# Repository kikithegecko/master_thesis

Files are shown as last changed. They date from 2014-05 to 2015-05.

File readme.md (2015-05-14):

### Casual Interation with a Bracelet

Yes, this is my Master thesis. It is about interaction with
a wrist-worn wearable (aka bracelet) and encompassed the
whole design and manufacturing process from the bracelet
itself to the needed electronics, some minituarization steps,
and of course the software. Oh, and the writing.

Here are some buzzwords if you're interested but want to know
if looking through all those files is really worth it ;)

- CAD models for 3D printing
- CAD models for liquid silicone cast
- PCB schematics for Teensy and Arduino shields
- Embedded code for a Bluetooth-controlled RGB light source
- A working implementation of the [3$ Gesture Recognizer](http://www.medien.ifi.lmu.de/pubdb/publications/pub/kratz2010threedollar/kratz2010threedollar.pdf) featuring 3-dimensional Golden Section Search
- A huge LaTeX writeup with lots of progress pictures
- Some slide sets to be used with reveal.js

If you're just interested in pictures, take a loog at my
[flickr profile](https://www.flickr.com/photos/kikidergecko/sets/), I have outsourced all pictures there.

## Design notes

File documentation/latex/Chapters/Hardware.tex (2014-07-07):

\chapter{Hardware}

\section{The Bracelet}

The bracelet consists mainly of an electronic ink display and several touch sensors for conscious interaction and a motion sensor for gesture recognition. The bracelet's design focuses on wearing comfort, low weight and small error of unintended activation.

\subsection{Design Process and Prototype Manufacturing}

The design process for the interactive bracelet presented in this thesis went through different stages. At first, a 3D-printed casing was favored, but later on a cast silicone bracelet turned out to be very comfortable for the user. The different prototypes are explained in detail in the following sections.

\subsubsection{Constant Thickness}

This very simple first approach is basically a rectangular profile rotated around a curve. It has the same magnitude at any point, which makes it quite uncomfortable to wear, especially under a layer of clothing.

\subsubsection{Tapered Shape}

With a tapered shape and non-uniform thickness, this looks more appealing. The reduced wall strength (0.7mm) made it very fragile in fabrication, two (out of two) prints broke during post-processing. Wearing the cuff while working on a PC feels only a little uncomfortable, but twisting the hand is encumbered by the tight-fitting bracelet. Future prototypes sould allow more space between the arm and the bracelet to ensure better comfort.

\subsubsection{Tapered Shape with Lid}

A modified design of Prototype 2 with a removable lid. The structure of the lid turned out to be too fine, especially the flexible part was too thin to work as intended. The size of the bracelet was increased a little so it is more comfortable to wear. Still, the rigid shape leads to clumsiness.

\subsubsection{Amico Bracelet Print-out}

Just a print of the tri-part design by Daniel Muschke on GrabCAD. It turned out to be a little too small, but the style felt more comfortable than the previous prototypes.

\subsubsection{Modified Tri-Part Design}

A re-work of Prototype 3, involving hinge research. The first draft turned out way too small, the second iteration was too big. Further research into this shape was paused because a long, bracelet-like display was considered instead of a small one.

\subsubsection{Silicone Bracelets}

After some consideration on a flexible, bracelet-shaped e-ink display, a prototype from silicone was considered. Mold design turned out a little tricky but finally succeeded. I printed a two-piece mold which only needed a little post-processing to fit properly together. The mold was coated with black spray paint to make the inside a little smoother, but this didn't work as intended so the paining step can be omitted in future mold making processes. The filling holes for the silicone were too small, and the silicone was more viscous than expected.

The first cast with a closed mold and filling through the holes was very unsuccessful, it produced two small end pieces and nothing in between. For following casts, one part of the mold was filled with silicone and closed afterwards, this turned out way better. It is also important in what orientation the mold is placed during dry period, because air bubbles will float towards the ``top'' of the mold, leading to instabilities. Getting the silicone part out of the mold was no problem.

The bracelet design involved a magnet clasp and it turned out as almost impossible to strongly attach magnets to silicone with anything but silicone itself and they will likely jump out of place and snap together if you place them too close in your design.

Two casts were made, one with each of the available silicone mixtures. The softer one was slightly too soft and had a disappealing color. No tests were made yet regarding the tightness of the diplay inside the bracelet.

\section{Interactive Light Source}

The examplary light source for the scenario mentioned at the beginning of this page will be an Arduino-controlled LED strip. Communication with the bracelet will take place via Bluetooth. An Arduino-controlled RGB LED strip with a Bluetooth module. For a color change, the RGB color code is transmitted in a RRRGGGBBB string. Note that all values must have 3 digits, leading zeroes must not be omitted.

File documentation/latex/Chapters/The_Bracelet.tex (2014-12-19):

\chapter{The Bracelet}
\label{chap:bracelet}
As presented in the introduction, this thesis aims to design and implement a wrist-worn wearable. Users should interact with it in a casual way, meaning that the interactions are not interrupting the users' current tasks in contrast to typical smartphone interactions that require focus on the display and input. Instead, the frequently used functions for controlling the ambient light should be executed without needing to look at the device, so that additional cognitive and physical load by either social, mental or physical encumbrance does not prevent the user from interacting with the bracelet.

In terms of hardware design, the device should be comfortable to wear, even for a longer period of time. To increase acceptance of potential users, the bracelet should not feel more clumsy than a wristwatch and the material has to be skin-friendly. Regarding the interaction design, gestured input as well as a touch sensor that enables sliding interaction need to be included. Although direct feedback of interaction is given by the controlled light source, a minimal form of visual feedback can help the user when in doubt about correctly triggering specific features. In order to communicate with the ambient light, the bracelet needs some form of wireless communication. The device's processor needs to be fast enough to analyze in-air gestures without perceptible delay.

Regarding those constraints, the interactive bracelet consists of several touch sensors, a motion sensor, a status \ac{LED} and a Bluetooth communication module, all powered by an ARM microcontroller. The bracelet's design focuses on wearing comfort, low weight and small error of unintended activation.

\section{Manufacturing Techniques}

All bracelets produced for this thesis were designed using a 3D \linebreak\ac{CAD} modeler. The first prototypes were 3D printed rigid bodies to wear as arm cuffs, but those designs turned out to be too inflexible and uncomfortable to wear. The need for a different material for the bracelets arose, so a transition from printing to casting with liquid silicone was necessary. The molds are printed, assembled, filled with silicone and usually destroyed while retrieving the finished cast.

This section will explain the various methods and tools used for designing and manufacturing the bracelet prototypes in detail.

\subsection{Computer Aided Design}
% http://www3.ul.ie/~rynnet/parametricmodellingbasics-solidworks.php
In the beginning of a design iteration, a model of the desired object is created with a 3D \ac{CAD} program. For all designs in this thesis, the open source \ac{CAD} modeler FreeCAD \cite{freecad} was used. This program classifies itself as a general purpose 3D parametric modeler. A typical work-flow when designing a bracelet is as follows:

A bracelet's model is based on a sketch defining the inner circumference of the future bracelet. As the human wrist does not follow a circular shape, all designs made for this thesis are based on an oval circumference. In FreeCAD, this is realized by a composition of arcs and straight lines. It is important to constrain the sketch with radii, lengths and angles as well as symmetries or perpendicular constraints until no degrees of freedom are left and thus the model is fully constrained. If the model is missing some constraints, the export process or the printing of the model can raise errors or alter the design in an unintended way.

In the next step one or more cross sections are added to various points along the circumference. They define the thickness and shape of the bracelet at said points. For increased comfort, the bracelet should be as slim as possible, especially on the ``backside'' below the palm. In more complicated designs, an alternative to complex sketches for the profiles is the creation of multiple, overlaid sketches as a preparation for a subtraction operation in the later process. All profiles need to be fully constrained as well.

\begin{figure}[bth]
	\myfloatalign
	\subfloat[Fully constrained inner circumference]
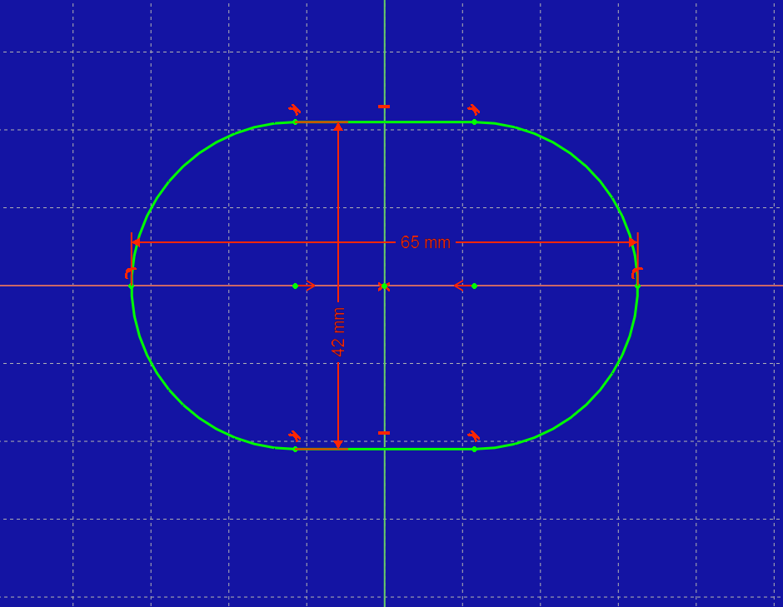
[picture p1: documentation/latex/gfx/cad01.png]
	{} \quad
	\subfloat[Added profile for sweeping around the circumference]
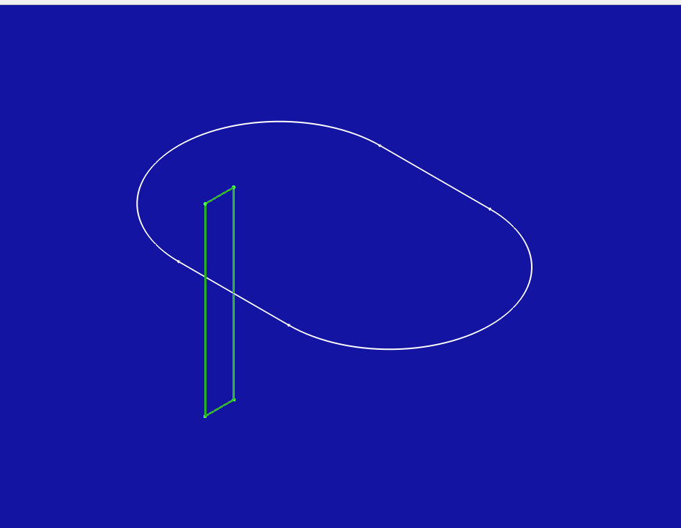
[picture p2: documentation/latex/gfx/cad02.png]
	{} \\
	\subfloat[Result after sweeping]
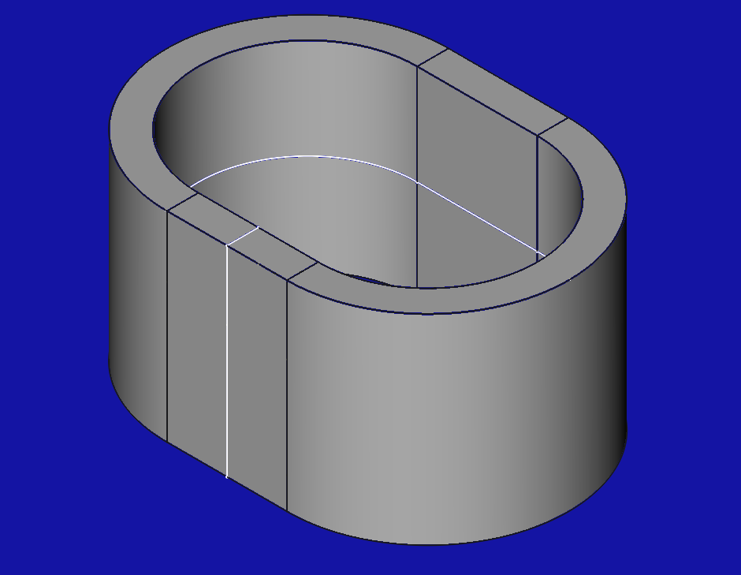
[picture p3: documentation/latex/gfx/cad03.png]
	{} \quad
	\subfloat[\ac{CAD} model after using a boolean subtraction operation]
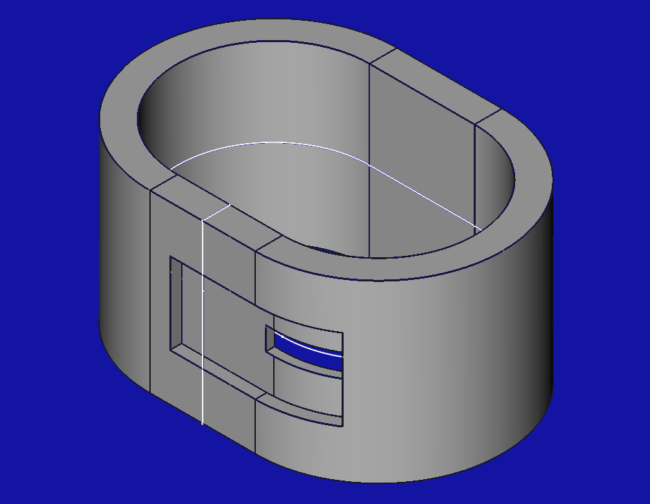
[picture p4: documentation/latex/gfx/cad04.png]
	{}
	\caption{Steps in designing a bracelet prototype in FreeCAD.}
	\label{fig:cad}
\end{figure}

After the circumference as well as one or more profiles are added to the design, a first solid is created by sweeping the profile(s) around the circumference curve. This operation creates a basic shape that can be refined further on, typically by chamfering or filleting the edges to increase wearing comfort. If a complex shape is desired, multiple sweeps can be generated and used in boolean operations such as union or subtraction. This is the usual approach for most bracelet designs. Figure \ref{fig:cad} illustrates these steps.

The last step in the design process is usually the finishing of the \ac{CAD} model. In case of the bracelet, this translates to edge smoothing with chamfer or fillet tools. Smoothed edges increase the overall wearing comfort of a bracelet, so they are very desirable on edges in contact with the skin.

The finished designs are then exported as mesh files (usually in \ac{STL} format) for printing.

\subsection{3D Printing}
All prints were manufactured using a ProJet360 3D printer \cite{printer}. The model is created by printing the binder fluid onto a plaster-like powder bed in the build area. After each printed layer, a new thin layer of powder is added to the print bed. The ProJet360 allows for a layer thickness of 0.1 mm \cite{datasheet_printer}. This allows even delicate structures without any additional supports, since the printed object is surrounded and therefore supported by plaster powder during the production process. The only drawback of this printing process is that it doesn't support closed, hollow objects since there is no possibility of removing the enclosed excess powder after the process has finished. When designing models for 3D printing, this constraint has to be kept in mind.

The finished object is then carefully removed from the build bed and any excess powder is gently brushed or blown off. The printer offers a cleaning chamber with a pressurized air pistol and a vacuuming system to assist in that task. Without further hardening, the objects are very fragile and easy to break, even with the pressurized air pistol included in the printer. In order to drastically increase the strength of the prints, they are infiltrated with a fluid after they were thoroughly cleaned. Prints produced by the ProJet 360 can be infiltrated with one of three different substances with varying characteristics: The ColorBond ``instant-cure infiltrant'', the two-part StrengthMax infiltrant ``ideal for functional models'', and the Salt Water Cure ``eco-friendly and hazard-free infiltrant'' \cite{datasheet_printer}. All prints produced for this thesis were infiltrated with ColorBond.

The infiltration step adds strength and hardens the material, resulting in a sturdy printed object. However, the objects created with this technique are very rigid and any bending load breaks them easily. Wall strengths of $1.5$ mm and up have been proven sturdy enough for a bracelet shape, although this also depends on the object geometry.

\subsection{Silicone Casting}
% http://www.npl.co.uk/science-technology/mass-and-force/hardness/rubber-hardness
% https://www.google.com/patents/US1770045
% http://www.calce.umd.edu/TSFA/Hardness_ad_.htm#3.5
% ISO 7619 for scale OO?
Another manufacturing process for bracelet prototypes used in this thesis is liquid silicone casting. Two different types of silicone were used for making various bracelet prototypes, both from manufacturer Smooth-On: Sorta-Clear 37 and Mold Star 15 Slow.

The most important characteristic for silicone in prototype production is the hardness, measured in Shore (after Albert F. Shore) or Durometer. It measures the indentation of a material with a special device which is also called Shore Durometer. It consists of a hardened steel rod with a finer tip and is available in two versions, since there are two different scales for Shore hardness (cf. table \ref{tab:shore}). The Shore A scale is designed for softer materials and the Shore D scale for harder ones, but they do overlap, so a material classified in Shore D hardness is not necessarily harder than another material classified in Shore A hardness. Each scale ranges from values 0 to 100, higher numbers indicate higher material resistance. The Shore hardness is specified in EN ISO 868.

\begin{table}
	\myfloatalign
	\begin{tabularx}{\textwidth}{clcc} \toprule
		\tableheadline{Type} & \tableheadline{Configuration} & \tableheadline{Diameter} & \tableheadline{Spring Force}\\ 
		\midrule
		A & $35\degree$ & $1.4$ mm & $8.06$ N \\
		D & $30\degree$ & $1.4$ mm & $44.46$ N\\
		OO & $1.2$ mm in spherical radius & $2.4$ mm & $1.11$ N \\
		\bottomrule
	\end{tabularx}
	\caption[Test setups for Shore hardness types]{Test setups for Shore hardness types A, D, and OO \cite{ASTM2240}}  \label{tab:shore}
\end{table}

When dealing with silicone, the Shore A scale is sometimes too ``hard'' for soft rubbers. Another standard therefore specifies twelve different Durometer types, where the OO scale is commonly used for soft silicones \cite{ISO7619}. Figure \ref{fig:shore} shows the three Shore hardness scales A, D, and OO, as well as some examples for everyday objects and their corresponding Shore values.

\begin{figure}[bth]
	
	\caption[Shore hardness scales and everyday examples]{Shore types A, D, and OO in comparison with everyday examples of various hardnesses. \cite{smoothon-web}}\label{fig:shore}
\end{figure}

The silicone rubbers used for casting bracelet prototypes are both located on the Shore A scale. The softer Mold Star 15 Slow has a Shore A hardness of 15 that could be roughly compared to that of a rubber band according to figure \ref{fig:shore}, while the slightly harder Sorta-Clear 37 has a Shore A rating of 37, similar to that of a pencil eraser \cite{moldstar} \cite{sortaclear}.

Both silicone products consist of two compounds that have to be added up and stirred before casting. While the Mold Star silicone has a rather low viscosity, casting the Sorta-Clear requires careful mold design, since it does not distribute well and is rather viscous. A vibrating table can help in filling the mold completely, but nonetheless were casts with the Sorta-Clear silicone much less fruitful, especially for the detailed molds of the one-piece designs (cf. section \ref{sec:silicone-prototypes}).

\section{Design Process and Prototype Manufacturing}

The design process for the interactive bracelet presented in this thesis went through different stages. At first, a 3D printed casing for the electronics was favored, but turned out to be too rigid, too fragile and even cumbersome while worn on the wrist. Later on, a cast silicone bracelet turned out to be more comfortable for the user. The different prototypes are explained in detail in the following sections.

\subsection{Rigid Designs}

The first approach that comes to mind when thinking about bracelet design is a cuff-like, rigid shape. From the\ac{CAD} point of view, the first bracelet prototype consists of a single rectangular profile rotated around a oval curve which was derived from a measured wrist. The bracelet's inside is hollow, in order to store all the electronic components. The cuff's gap was just large enough for the wrist to fit through, although in reality, this lead to light scratches on the skin in combination with the rough texture of the printed material. In addition, the uniform thickness made this first prototype uncomfortable to wear, especially at the open ends. 

To summarize, the uniform thickness made the bracelet feel uncomfortable on the wrist and the material felt unfriendly to the skin. So this fist prototype had some clear downsides that were eliminated in the next iteration.

\begin{figure}[bth]
	\myfloatalign
	\subfloat[\ac{CAD} view]
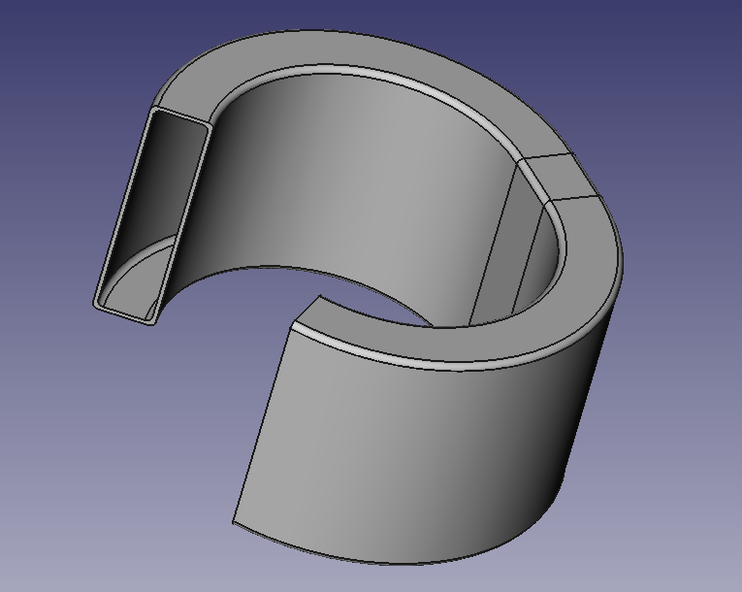
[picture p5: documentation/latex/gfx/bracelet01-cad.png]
	{} \quad
	\subfloat[Printed bracelet]
	{\label{fig:bracelet01}%
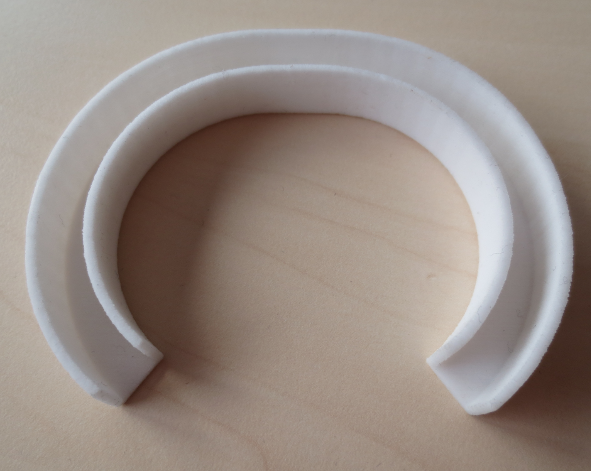
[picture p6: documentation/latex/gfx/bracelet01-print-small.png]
	}
	\caption{First rigid design with uniform thickness}
\end{figure}

In the following iteration, a bracelet of varying thickness was designed to make wearing the prototype more comfortable. The part on top of the wrist was designed to have the highest thickness, since this spot is only rarely disturbing in typical wrist movements and users are likely accustomed to some extra mass on this spot from wearing wristwatches. As the bracelet bends around the arm, its thickness decreases and shrinks to a minimum at the cuff gap. Decreasing the thickness from $10$ mm to $3$ mm made the look more appealing and wearing a little less encumbering. At the same time, the wall strength was decreased from $1$ mm to $0.7$ mm, which made it very fragile in fabrication and usage: Both prints broke during post-processing. Additionally, the possibility of storing electronic components inside the bracelet decreased, since smaller ends featured smaller entrances to the hollow inside. Wearing the cuff while working on a PC felt only slightly uncomfortable, but twisting the hand was still encumbered by the tight-fitting bracelet. 

All in all, a tapered shape felt more comfortable, but the downsides of the material were still present and the improved shape led to less practicability from the engineering point of view. A design goal for future prototypes derived from this prototype was adding more space between the arm and the bracelet to ensure better comfort while wearing it.

\begin{figure}[bth]
	\myfloatalign
	\subfloat[\ac{CAD} view]
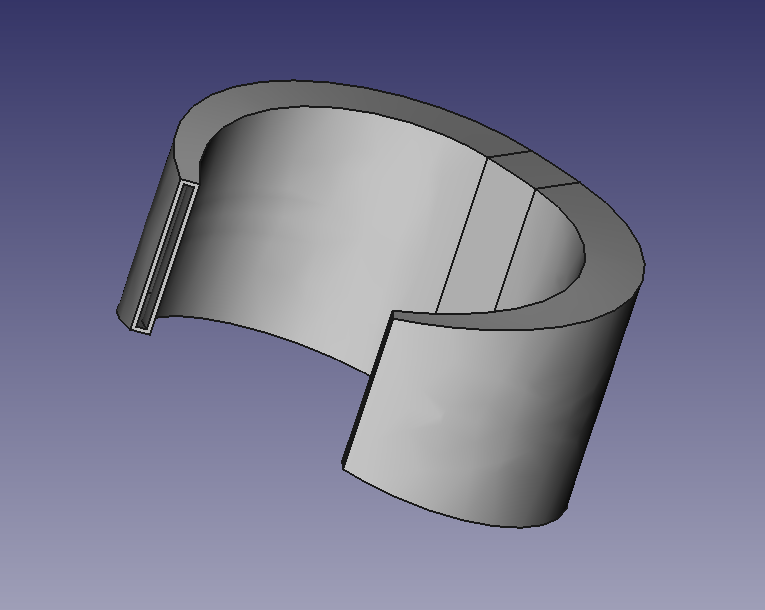
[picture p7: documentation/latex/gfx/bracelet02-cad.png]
	{} \quad
	\subfloat[Printed bracelet]
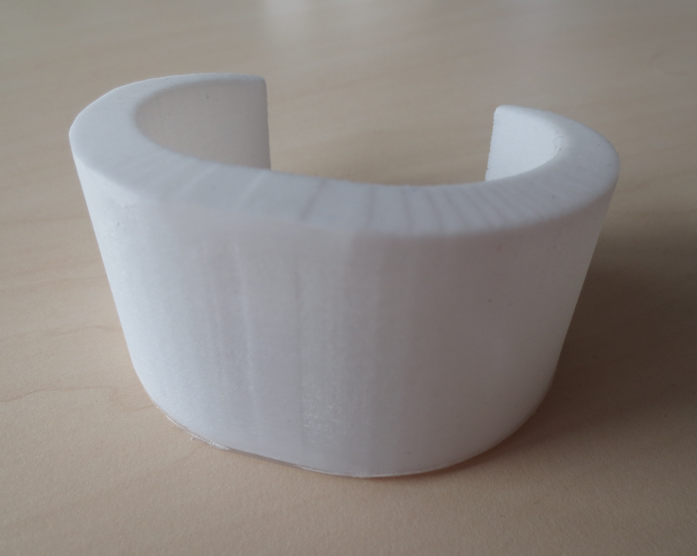
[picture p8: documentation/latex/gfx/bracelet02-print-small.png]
	{} \\
	\subfloat[Top view]
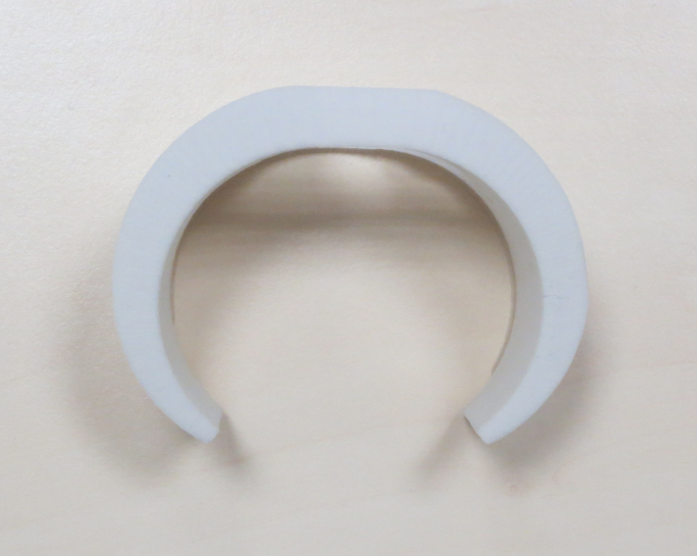
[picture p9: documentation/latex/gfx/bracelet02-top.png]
	{} \quad
	\subfloat[End detail]
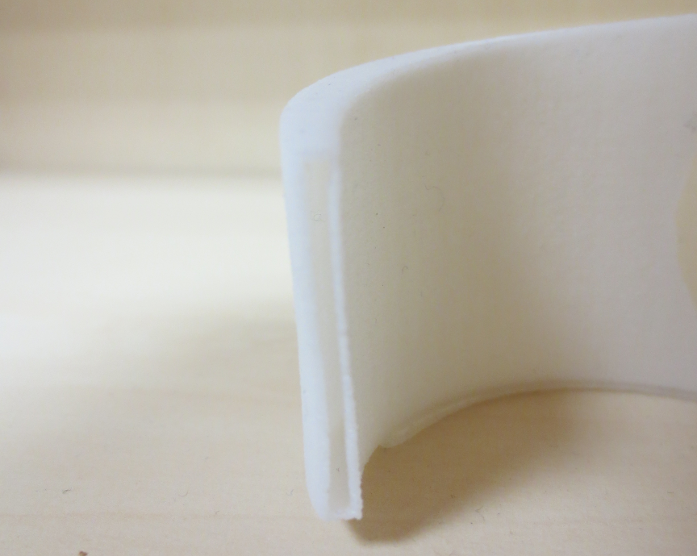
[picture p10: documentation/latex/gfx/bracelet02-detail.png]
	{}
	\caption{Second design featuring a tapered shape}
	\label{fig:bracelet02}
\end{figure}

A modified design of the aforementioned prototype featured a removable lid since the tapered shape made it hard to access the inside space of the bracelet. The lid design was inspired by battery case covers commonly found in remote controls or small electronic devices. It features two rabbets on the one side that support the lid in its place and another, smaller rabbet with a cavity in the material right next to it, so the rabbet can snap just inside the lid gap when it closes.

\begin{figure}[bth]
	\myfloatalign
	\subfloat[Lid in \ac{CAD} view]
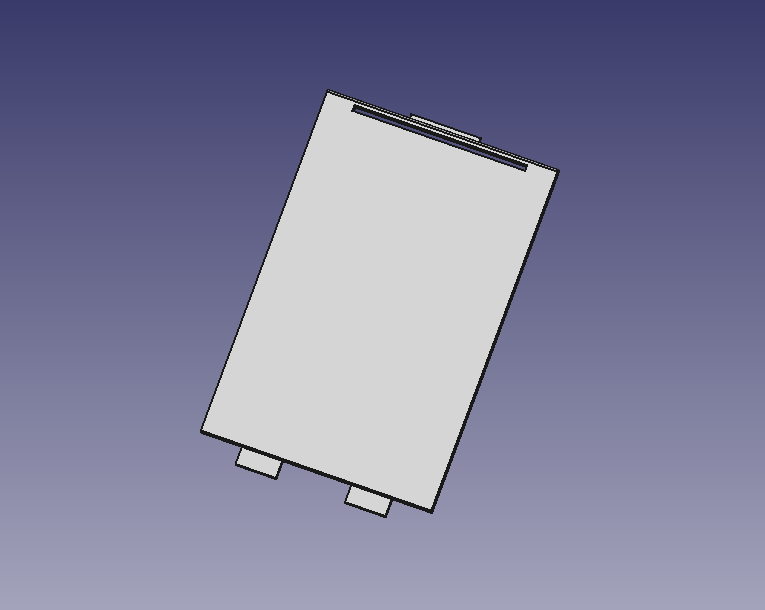
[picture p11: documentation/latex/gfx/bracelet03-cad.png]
	{} \quad
	\subfloat[Printed bracelet]
	{\label{fig:bracelet03}%
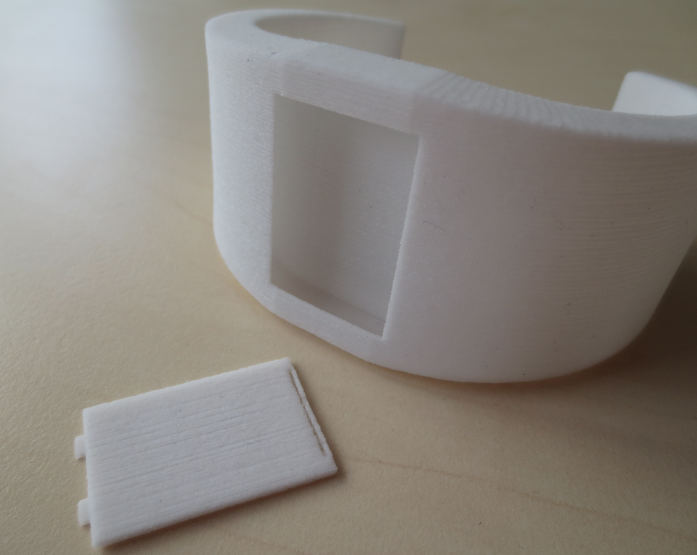
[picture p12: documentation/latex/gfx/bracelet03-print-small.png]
		}
	\caption{Third design with removable lid}
\end{figure}

It turned out that the lid features were designed too finely, especially the flexible part was too thin to work as intended. The lid had to be opened and closed very cautiously and overall, the construction seemed not reliable for daily use. In addition, the rigid shape still lead to clumsiness in wearing the bracelet, so the whole concept of rigid bracelets was abandoned.

\subsection{Segmented Designs}

The search for a more flexible printed bracelet shape lead to an entry for an activity bracelet design contest by Daniel Muschke on a 3D printing template exchange site called \textit{GrabCAD} \cite{amicobracelet}. Muschke created a \ac{CAD} file for a bracelet consisting of three segments that are connected by slow hinges, i.e. hinges with great resistance that do not move if no external force is applied. This design considered electronic components like a micro-controller and a micro \ac{USB} port which made a good start for further modification, but unfortunately the file format made it impossible to alter the design in detail. A print was possible since \ac{STL} files were included in the upload. However, the design turned out to be too small to be actually wearable, but it demonstrated that printed hinges work well with a pivot made from wire. The style felt more comfortable to wear than the previous prototypes and felt leaner on the wrist than the rigid prototypes. Overall, the printed design looked promising so the idea of a multi-part bracelet was investigated further.

Recreating Muschke's design was not as easy as planned, since the parametric modeling approach on this segmented shape was very different compared to previous designs. The first prototypes were based on a wrist-like oval circumference curve, while the multi-part design originated from a partitioned circle, since all parts should have the same dimensions in length and curvature. Adjusting the part size to the designated wrist turned out to be difficult, and prints of the design were either too small or too big when printed.

The bracelet segments are hollow and open on the side that lays to the wrist. This leaves enough space for storing electronics. Since the parts are only connected by hinges, routing the necessary wires between the segments needs to be considered, e.g. by leaving small holes right next to the hinges.

\begin{figure}[bth]
	\myfloatalign
	\subfloat[\ac{CAD} view]
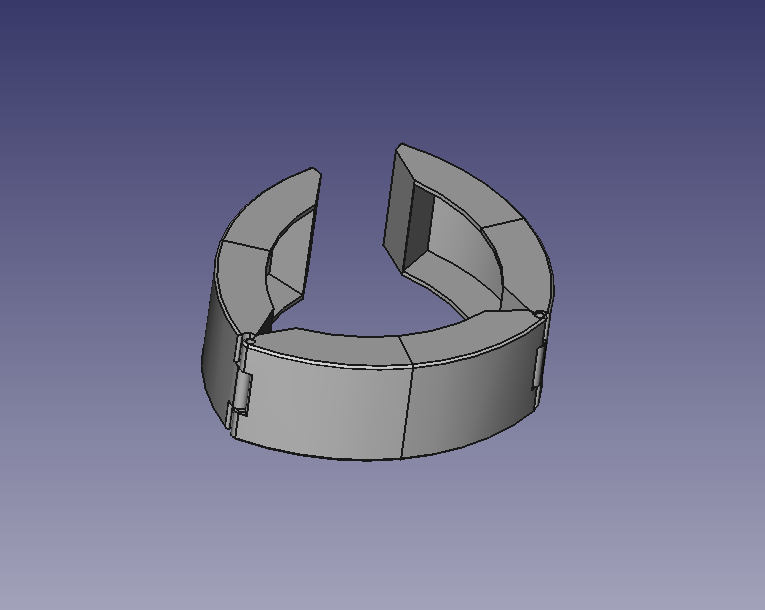
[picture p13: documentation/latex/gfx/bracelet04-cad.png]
	{} \quad
	\subfloat[Hinge Detail]
	{\label{fig:bracelet04}%
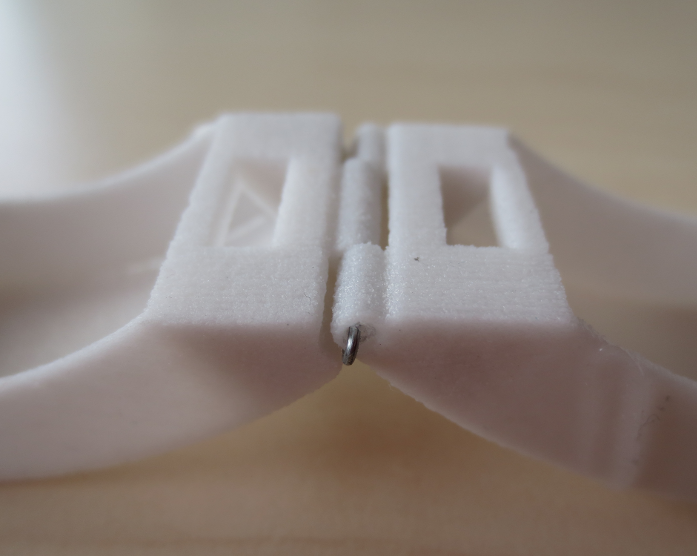
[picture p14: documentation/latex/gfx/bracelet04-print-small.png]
		}
	\caption{Multi-part design}
\end{figure}

Since the manufacturing possibilities at the \ac{HCI} group don't allow for slow hinges (as the inspiration by Muschke suggests), a different solution for keeping the bracelet closed while worn on the wrist needed to be found. A magnet clasp with small neodymium magnets was tested, but attaching them turned out to be more difficult than expected. When attached to the inside of the segment tips, the magnetic force was too weak to reliably keep the bracelet together. Mounting the magnets on the outside of the segments resulted in mounting difficulties, since the magnetic force of neodymium magnets is considerably strong,  which frequently resulted in torn glue layers.

When an electrophoretic display was considered as a part of the bracelet, the segmented approach became undesirable, since in addition to aforementioned difficulties during design and manufacture, the usable surface space was relatively small when it came to hosting a single big component like a display. This issue led to further research into various other manufacturing techniques and potential materials for bracelet prototypes, and, eventually, to cast silicone.

\subsection{Silicone Bracelet}
After some consideration on a flexible e-ink display, a prototype brace\-let made of silicone was considered. The molds used in the casting process were designed and printed similarly to the bracelets presented in the previous sections. However, designing a mold was significantly more difficult.

As with the previous 3D printed prototypes, the bracelet positive was designed first. The flexibility of silicone allows for some features that weren't practical when implemented in rigid material, such as e.g. cavities for electronic components. This resulted in more complex bracelet concepts. In addition, closing mechanisms like magnets had to be considered in this design stage.

When the \ac{CAD} process for the positive is finished, the mold is designed by adding surrounding geometries to the model and applying boolean difference operations. If reusability is desired for individual mold components or the whole mold, the geometry and constellation of the mold parts need to be planned carefully; therefore the characteristics of the printed material have to be taken into consideration. For example, tunnels in the resulting silicone bracelet are not possible if the mold is meant to be used more than once.

Another important aspect of mold design is planning the casting process. Some types of silicone rubber are more viscous than others, and the mold design needs to make sure that the liquid rubber reaches all corners and delicate parts well. The distribution inside the mold can be supported by applying gentle vibration during the cure process. However, this assumes that the liquid silicone is already distributed into most regions of the mold.

The first silicone design was a simple strap with an open pocket for the long electrophoretic display which was considered as a feature of the bracelet at that time in the design process. The closing mechanism relied on molded neodymium magnets for which some cavities were featured in the bracelet design.

Mold design turned out a little tricky but finally succeeded. A two-piece mold was printed which needed a little post-processing to fit properly together. To ensure a proper fit when closed, small tongues and grooves were added to the mold parts. The mold's inside was coated with black spray paint to make it a little smoother, but this didn't work as intended so the painting was omitted in future mold making processes. The filling holes featured for the silicone were too small, and the mixture was more viscous than expected, so the first cast failed and resulted in two small end pieces and nothing in between. Figure \ref{fig:silicone01} (a)-(c) illustrates some steps in this process.

\begin{figure}[bth]
	\myfloatalign
	\subfloat[Unpainted molds]
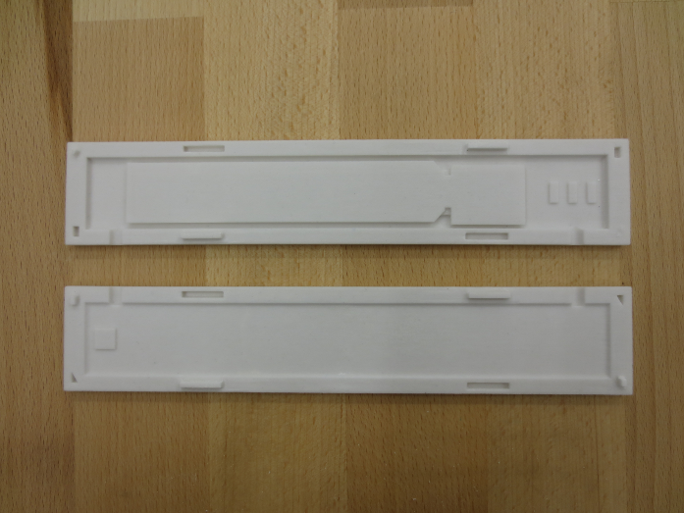
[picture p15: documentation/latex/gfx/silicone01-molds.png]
	{} \quad
	\subfloat[Closed molds with filling holes]
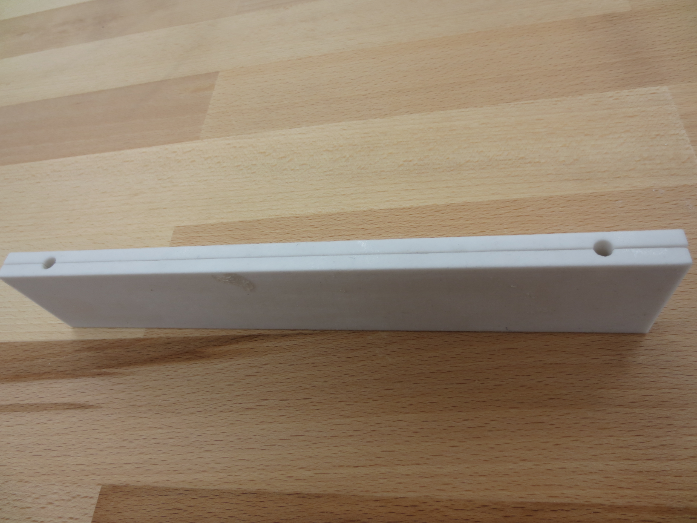
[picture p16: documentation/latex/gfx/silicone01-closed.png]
	{} \\
	\subfloat[Result after first cast through filling holes]
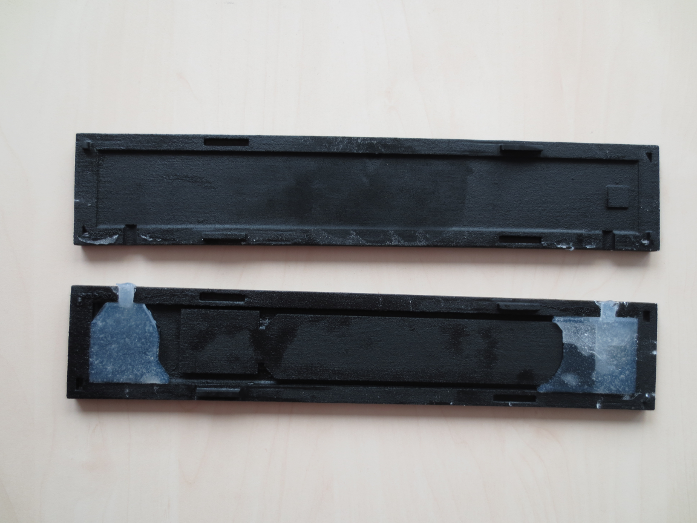
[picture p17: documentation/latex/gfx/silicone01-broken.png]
	{} \quad
	\subfloat[Result after second cast by filling the mold directly]
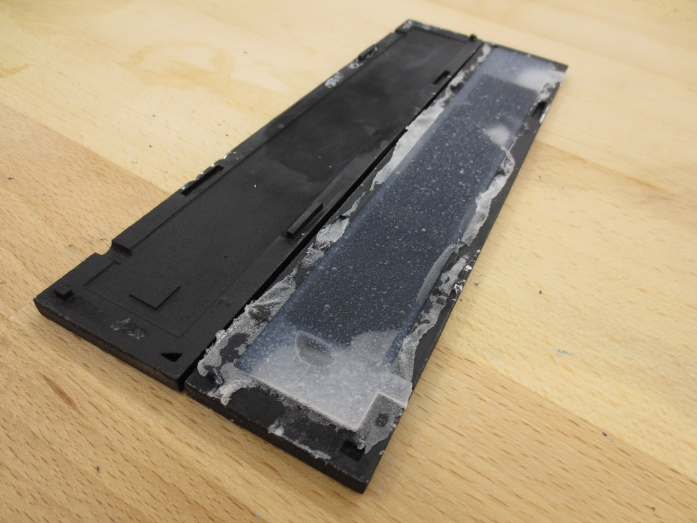
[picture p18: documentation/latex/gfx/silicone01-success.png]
	{} \\
	\subfloat[Successfully cast bracelet]
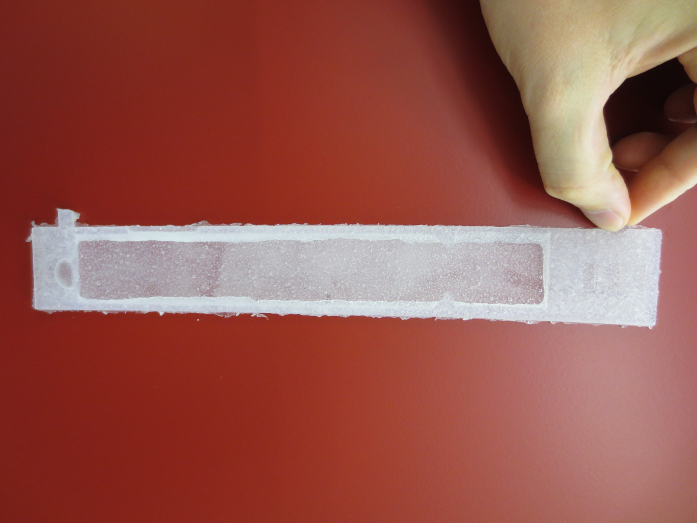
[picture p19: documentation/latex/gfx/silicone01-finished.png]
	{} \quad
	\subfloat[Bracelet with attached magnets]
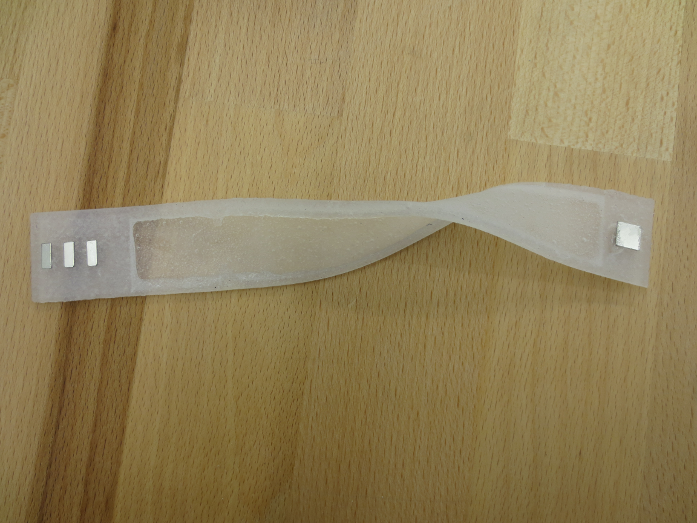
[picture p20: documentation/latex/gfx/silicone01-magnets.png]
	{}
	\caption{Manufacturing of a silicone bracelet using a two-piece mold}
	\label{fig:silicone01}
\end{figure}

For following casts, one part of the mold was filled with silicone and closed afterwards; those casts turned out significantly better (cf. \ref{fig:silicone01} (d)-(e)). The orientation in which the mold is placed during the dry period is also relevant, as air bubbles would float towards the ``top'' of the mold, leading to instabilities when oriented inappropriately. After the liquid silicone's curing period, retrieving the cast from its mold was unproblematic.

This first rubber bracelet design involved a magnet clasp (see fig. \ref{fig:silicone01} (f)), but it was infeasible to reliably attach magnets to silicone with anything but silicone itself and they would likely jump out of place and snap together if placed too closely to each other in the design. Apart from that, the silicone felt much more comfortable on the skin and was perceived as less obstructive while worn on the wrist. The possibility of attaching components by placing them in pockets or cavities resulted in thinner bracelets in general.

Two casts were made, one with each of the available silicone mixtures. The softer one was slightly too soft and in addition, the rims were too short, so the display would jump out of place almost instantly when bending the bracelet. With this knowledge and the positive impressions of the material itself, more silicone designs were produced and manufactured.

\subsection{One-Piece Silicone Bracelet}
\label{sec:silicone-prototypes}
The next design was a ring-like silicone bracelet in one piece, so the issue with closing mechanisms became obsolete. The mold for this prototype consisted of three pieces, an outer and an inner ring as well as a bottom plate to properly align those rings. Due to the very rigid printed material, the molds could not be recovered after the cast and had to be destroyed in order to retrieve the bracelet. To prevent unnecessary waste of material, the wall strength was reduced to $2.5$ mm, which turned out to be strong enough to survive assembly and the casting process. The advantage of using one-time molds was the possibility to add tunnels to the design. This was used in some models, especially for the display area to hide cables or bulky connectors. Figure \ref{fig:bracelethistory} gives an overview of the various design iterations.

\begin{figure}[bth]
	\myfloatalign
	\subfloat[The first design featured a large cavity for a flexible electrophoretic display]
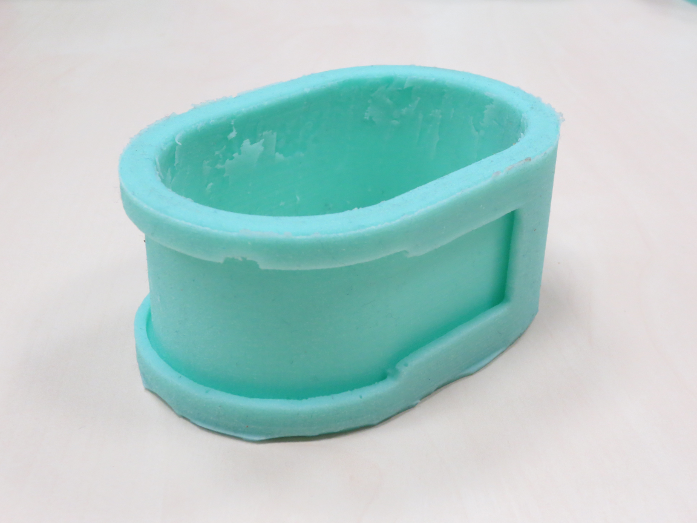
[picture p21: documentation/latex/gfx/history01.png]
	{} \quad
	\subfloat[The second design introduced a small tunnel]
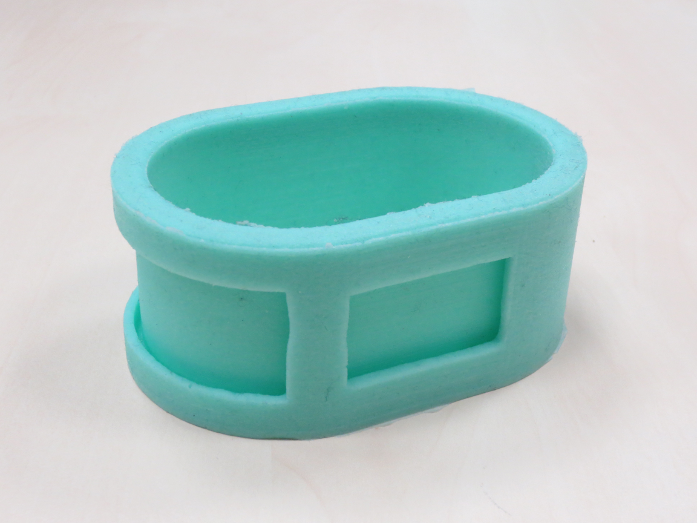
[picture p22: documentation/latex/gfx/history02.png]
	{} \\
	\subfloat[The third design replaced the display by a touch strip and featured a cavity for the Teensy]
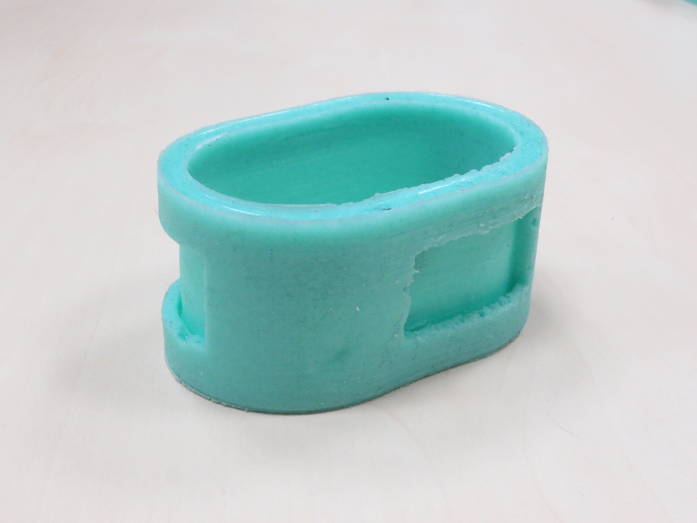
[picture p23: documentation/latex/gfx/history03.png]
	{} \quad
	\subfloat[The final design with varying thickness and a big cavity for the Teensy]
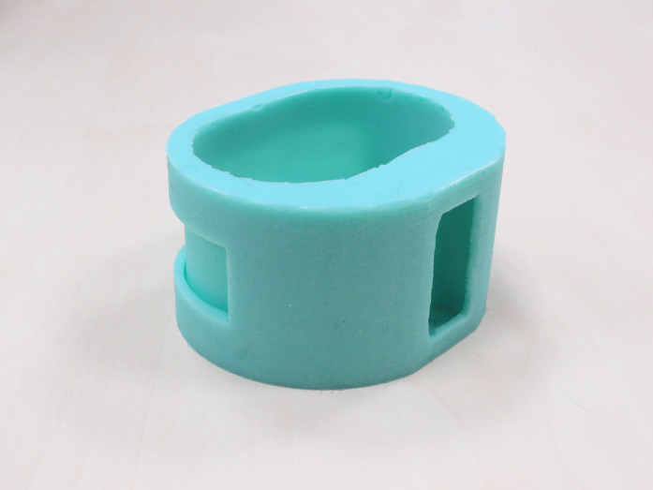
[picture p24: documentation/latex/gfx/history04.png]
	{}
	\caption{History of the one-piece bracelet prototyped manufactured for this thesis}
	\label{fig:bracelethistory}
\end{figure}

The molds for one-piece bracelets were harder to fill with material than the previous one. Especially the Sorta-Clear silicone was too viscous to fill the complete mold, resulting in broken casts. The green MoldStar silicone turned out to work quite well, but sometimes it would leak through little gaps between the rings and the base plate, so a thorough assembly was vitally important. Remaining gaps were closed with hot glue in later iterations. In addition, a simple self-made vibrating plate helped distributing the silicone to all parts of the mold and reduced the number of air bubbles in the cast. 

The first one-piece bracelet designs included an electrophoretic display and featured wide cavity rims to hold said display in place. First wearing tests were successful. When the display was omitted later on, the cavities stayed to hold a capacitive touch surface in place. After the final hardware configuration took form, another cavity for the electronics was added to the design. Since the hardware was thicker than the bracelet, the spot to house it needed to come thicker. The board was eventually placed on the inner wrist and connects to the touch element with a short flat wire cable along the bracelet's surface. It is powered by a micro USB cable attached to a port on the lower rim of the bracelet. A status \ac{LED} is visible through the silicone on the upper rim above the electronics.

\begin{figure}[bth]
	\myfloatalign
	\subfloat[Front view]
	{} \quad
	\subfloat[Back view]
	{} \\
	\subfloat[Top view]
	{} \quad
	\subfloat[Incorporated electronics]
	{} \\
	\subfloat[Teensy with custom shield]
	{}
	\caption{The final bracelet prototype}
	\label{fig:siliconefinal}
\end{figure}

\section{Teensy Development Board}
The core part of the bracelet's electronics is the Teensy USB development board, which is built around a MK20DX256 32 bit ARM Cortex-M4 Processor running on 72 MHz clock speed \cite{teensy_web}. The Teensy can be programmed using the popular Arduino IDE and thus can profit from the extensive existing libraries and code examples for the Arduino family.

Like many Cortex processors, the Teensy's chip has direct capability to process capacitive touch input. It also features the \ac{I$^2$C} protocol for communication with other components (see also section \ref{sec:accel}), several serial communication ports and an integrated programmer to enable flashing via \ac{USB}. However, the processor includes no floating point computation unit, which slows down calculations that feature floating point numbers.

\section{Touch Slider}
The major input interface of the bracelet is a touch surface which consists of seven cut copper foil segments that are placed in a zigzag pattern (cf. figure \ref{fig:sketch-touch}). This capacitive strip can either be used as an array of seven individual buttons or as a single large surface that can detect swiping gestures or a primitive variant of multi-touch interaction.

\begin{figure}[bth]
	\myfloatalign
	\begin{center}
	
	\end{center}
	\caption{Sketch for the capacitive touch slider}
	\label{fig:sketch-touch}
\end{figure}

Capacitive touch is based on the concept of a parallel plate capacitor. The copper foil segments act as a capacitor's plate, the human hand touching them represents the other plate. Since the capacitance is proportional to the area of the plates, larger segments lead to increased sensitivity. The definition of a plate capacitor's capacitance $C$ is defined as follows:
\[
	C = \frac{A\epsilon}{d}
\]
Where $A$ represents the area of the plates, $\epsilon$ is a material constant of the dielectric between the plates and $d$ is the distance between the plates. This shows that the capacitance changes more when the finger is close to the sensor and less when it's farther away \cite{Camacho2010}.

Touch sliders can be compared to a potentiometer and return an analog value for the finger's position on the slider \cite{Camacho2010}. The usual layout of a touch slider features several neighboring electrodes, in the context of this thesis, a slider with seven electrodes was designed and built. This option was chosen since the Teensy has a restricted number of capacitive sensing enables pins from which some were already in use for other components, since almost all pins of the chip serve multiple functions.

\begin{figure}[bth]
	\begin{center}
	
	\end{center}
	\caption{The capacitive touch strip used in the final bracelet prototype.}\label{fig:touch}
\end{figure}

A zigzagged pattern of the slider's electrodes supports microstepping, i.e. considering the logical combinations of multiple electrodes pressed at the same time to achieve a higher resolution in position detection \cite{Camacho2010}. The touch slider used in this thesis was made using an electronic vinyl cutter with copper tape. The slider is depicted in figure \ref{fig:touch}.

\section{3D Accelerometer}
\label{sec:accel}
Another interaction interface of the bracelet is a MMA8652FC three-axis digital accelerometer \cite{datasheet:mma8652}. In a micromachined device like the one used in this thesis, a seismic mass is attached to delicate ``springs'' in order to measure the acceleration. Both components are usually made of silicon. When an acceleration occurs, the electric capacitance between the seismic mass and the fixed frame changes and the occurring acceleration can be derived accordingly. Note that one such mechanism is only able to detect acceleration along a single axis. Since the MMA8652FC is a three-axis accelerometer, it contains one mass-spring-system for each of the three axis.

\begin{figure}[bth]
	\myfloatalign
	
	\caption[Block diagram of the MMA8652FC digital accelerometer]{Block diagram of the MMA8652FC digital accelerometer \cite{datasheet:mma8652}} \label{fig:accel}
\end{figure}

In addition to this basic accelerometer functionality, the MMA8652FC also features a range of embedded microprocessing functions, as depicted in the component's block diagram (fig. \ref{fig:accel}). Out of those functions, the ``Single, Double \& Directional Tap Detection'' was used predominantly. This module can detect tap interactions, which can be visualized as spikes in the acceleration along one specific axis. The detection process can be configured in detail to adjust factors like the tap intensity or the duration between the two taps of a double tap. When tap detection is enabled, a single register's content indicates if such a tap has occurred. The detailed configuration used for single and double tap recognition in context of this thesis is discussed in section \ref{sec:config}.

In order to communicate with the bracelet's processor, the accelerometer implements the \ac{I$^2$C} communication protocol which was developed in 1982 by Philips Semiconductor (now NXP Semiconductors) and became public domain in 2006 when the underlying patent expired. By using two lines for a clock signal (\textsc{SCL}) and data transmission (\textsc{SDA}) respectively, data can be interchanged in a master-slave system at varying bit rates. Figure \ref{fig:i2c} illustrates this process. To initiate communication, the Teensy incorporates the role of a master device and begins a transmission by changing the \textsc{SDA} value from high to low while \textsc{SCL} is on high. Now the bus is considered busy until the master sends the Stop condition and the actual data request and transmission can take place.

\begin{figure}[bth]
	\myfloatalign
	
	\caption[Data transfer on the \ac{I$^2$C} bus]{Data transfer on the \ac{I$^2$C} bus \cite{i2c}} \label{fig:i2c}
\end{figure}

To request register data from the accelerometer, the master writes the address of the desired register on \textsc{SDA}. Note that no further synchronization between master and slave device is needed, since the slave adapts the clock signal on \textsc{SCL} which is determined by the master device. After sending the register's address, the Teensy indicates the end of the transmission without sending a Stop signal. The accelerometer acknowledges the received data and proceeds to send the requested register's contents, and finishes by terminating the connection with a Stop command, which is generated by switching \textsc{SDA} from low to high while \textsc{SCL} is on high. Both lines now stay high due to connected pull-up resistors. If the next register's content is requested, the process starts again with a Start signal transmitted by the master \cite{i2c}.

\section{Visual Feedback}
To provide visual feedback to the user, an \textsc{RGB} \ac{LED} is incorporated in the bracelet. Since most changes are reflected by the connected light source with no perceptible delay, the \ac{LED} serves mainly as an indicator for the recognition of single and double taps in the context of precise color changes and gesture recognition.

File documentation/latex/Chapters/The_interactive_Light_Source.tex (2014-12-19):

\chapter{Interactive Light Source}
\label{sec:lamp}

The previously mentioned light source for the scenario is built around a 12 V powered RGB \ac{LED} strip, which can be purchased for home lighting or car decoration. It is approximately $5$ m long and features three \ac{LED}s on each $5$ cm long segment. The original controller box which included an \ac{IR} receiver for a remote was removed and replaced by an Arduino Uno \cite{arduino_uno} with a custom shield. 

The shield features a Roving Networks RN42 Bluetooth module \cite{datasheet_rn42} and some transistors for switching the voltage on or off. The whole setup is powered by a standard 12 V power supply and encased in a spherical lamp shade made from translucent glass in order to diffuse the spotted impression of the LED strip (cf. figure \ref{fig:lamp}).

\begin{figure}[bth]
	\begin{center}
		
	\end{center}
	\caption{The interactive light source, encased.} \label{fig:lamp}
\end{figure} 

Communication with the bracelet takes place via Bluetooth. The RN42 module implements the Bluetooth \ac{SPP} and can be accessed easily with the \texttt{SoftwareSerial} module from the Arduino standard library. The lamp is configured as a Bluetooth slave, the bracelet acts as the master device. For command transmission, a serial connection is established over the Bluetooth link between the devices. Once it is set up, the master transmits a nine-digit string composed from three values from $000$ to $255$. Note that all values must have three digits, leading zeros must not be omitted. These values represent the intensities of the red, green, and blue channel respectively. The algorithm on the Arduino feeds them into the platform's analog outputs which feature \ac{PWM}. These outputs are connected to the red, green, and blue channels of the \ac{LED} strip and so the light color changes. A simple fading algorithm prevents disruptive flashing while switching colors.

It turned out that the RGB \ac{LED}s use a lot of current, a test with an adjustable power supply yielded that the lights become much brighter with increased current. The power supply was limited to $5$ Ampere and there was no saturation in brightness indicated at this level. However, the standard power supply mentioned above serves only $2250$ mA which results in less brightness. A way to improve this would be to shorten the \ac{LED} strip by cutting off several segments.

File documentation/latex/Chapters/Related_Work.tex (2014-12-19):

\chapter{Related Work}
Casual interaction has been explored by other researchers.

Pohl and Murray-Smith have researched casual interaction with everyday electronics like smartphones. They coined the term ``casual interaction'' in contrast to focused interaction. They described that in many situations in daily life, the user would not receive periodic feedback from the interacting device or not interact with it in a constant, uninterrupted fashion due to physical, social or mental reasons like wearing gloves in the winter or being exhausted after a day of work. Instead of giving up control over the device in such situations, the user should be able to control the level of focus to which they would like to engage \cite{Pohl2013}. The underlying distinction between foreground and background interaction in the context of technology has been introduced by Buxton in 1995, where he described improvements on telemetry systems. As a background interaction between humans, the office cameras of the system's participants take periodic stills and check if all members of a scheduled video conference are at their desks. Once all participants are available, the software actively asks to set up a conference and thus switches to foreground interaction. This relieves the user of periodically interrupting her work and checking if all participants are available \cite{Buxton1995}.

Interaction with intelligent lighting in public space as well as in the arts has been researched by Seitinger et. al. The \textit{Urban Pixels} project encouraged users to interact with flexible \ac{LED} light sources which pose an alternative to current urban display systems \cite{Seitinger2009}, while the \textit{Light Bodies} project focused on people's interactions with and reactions to portable light sources that respond to sound and vibration \cite{Seitinger2010}. In both cases, the users enjoyed manipulating the lights and were eager to interact with them, often in a playful fashion.

Wearable electronic devices have been very present in the recent years. Activity trackers like the Fitbit bracelets \cite{fitbit} record the wearer's movement data and calculate statistics on daily activity, e.g. the number of stairs the user has climbed or the distance she rode by bicycle. Activity trackers thus aim to help the wearers in getting to know their daily habits and reaching goals in personal activity. Smart watches connect to mobile phones using Bluetooth, they display various notifications along with the current time, allow for music playback control or aid in navigational tasks. They are either universal like the Pebble \cite{pebble} or bound to a certain phone like Samsung's Galaxy Gear \cite{galaxygear}.

More recently, attempts to add ``social'' features to wrist-worn smart devices have been made. The \textit{iBand} concept by Kanis et. al attempts to augment virtual social networks by merging their information about a person into real-world interactions with people. The device  triggers an automatic exchange of contact information if two users perform a handshake. Furthermore, the user can personalize a displayed logo and ``collect'' other users' emblems by exchanging contact information with them \cite{Kanis2005}. As a commercial product, the Razer Nabu smart band can exchange contact information on a handshake and detect other nearby users. The product merges these ``social'' functions with an activity tracker as described above \cite{razernabu}.

Controlling devices in the smart home is mostly realized by trigger-action programming as discussed by Ur et. al. On the IFTTT platform, users can create simple ``if, then'' rules for linking a broad range of actions between different software or devices, allowing only one trigger and only one action per rule. Ur et. al. discovered that a model like this for expressing rules would suffice to formulate behavior for the smart home if more flexibility in formulating the rules was allowed \cite{Ur2014}. A more complex approach to controlling the smart home is the use of middleware like \textit{Android Wear} for customized applications and use of an app store, allowing to pick the right applications for the smart home components available \cite{androidwear}.

Regarding new shapes and configurations of wrist-worn wearables, research has come up with various concepts. The \textit{Facet} bracelet features multiple displays and allows users to rearrange apps between them or extend a single app over multiple segments \cite{Lyons2012}. Kim et. al. implement remote control of other devices by performing hand gestures which are recognized by the \textit{Gesture Watch}, a set of proximity sensors worn on the wrist \cite{Kim2007}. The \textit{Snaplet} flexible touch display consists of an electrophoretic display augmented by sensors that can detect the current shape of the device. Bending the display causes \textit{Snaplet} to change its function (e.g. phone, media player) or allows the user to navigate through menus \cite{Tarun2011}. Ni and Baudisch even suggest reducing the size of the wearable device to a tiny worn sensor that uses the surrounding skin on the arm or any other body part as an input canvas for touch and gesture input, so that the device blends in with the user's clothing or skin. Despite their small size, users are still able to issue various commands and enter text by using a graffiti gesture alphabet \cite{Ni2009}.

For gesture recognition, two major algorithms that originate from the field of machine learning are very present in research projects. The Gesture and Activity Recognition Toolkit \textit{GART} has been developed by Lyons et. al. and is based on Hidden Markov Models, a statistical model also used in fields like speech or writing recognition \cite{Lyons2012}. \textit{GART} has been used by the aforementioned \textit{Gesture Watch} \cite{Kim2007} and the \textit{AirTouch} device, an around-device gesture recognition device that gives tactical feedback in form of vibrations \cite{Lee2011}. Several other gesture recognizing wearables implement Dynamic Time Warping, another algorithm from the field of machine learning that matches temporal sequences that very in speed \cite{Ashbrook2010} \cite{Liu2009}. In contrast to those computation-heavy and complex algorithms, Wobbrock et. al. have developed a simpler, geometry-based gesture recognizer for touch screen interaction that compares shapes against templates by scaling, translating and rotating them while measuring the distance to find a minimum \cite{Wobbrock2007}. The algorithm was extended to 3D accelerometer data by Kratz and Rohs \cite{Kratz2010}. The recognizer was designed as easy to implement and functional even on embedded devices with limited computation capabilities.

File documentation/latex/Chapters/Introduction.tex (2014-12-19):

\chapter{Introduction}
\label{sec:intro}
Today, Smartphones are our digital assistants for of daily life, and at present, wrist-worn wearables are emerging to take the interweaving of online and offline life one step further. This comes with many advantages and new possibilities, but also amplifies current issues in daily life with those gadgets. While those devices often call the attention of the user, their design around a touch-enabled screen forces the user to concentrate on the device while interacting with it. This usually distracts the user from his or her current context in daily life and forces him or her to interrupt the current task in order to interact with the device \cite{Pohl2013}.

As explained previously, interaction usually requires the full attention of the user. This doesn't suit the way we use our electronic devices in daily life. Since the user is not always able or willing to fully focus on a device, most mobile interaction is perceived as annoying or interrupting, since it often interrupts all other things the user is doing at that moment. Due to physical, mental or social obstructions, which can be either temporary or permanent, a user might not be able to interact with a device as intended \cite{Pohl2013}. This can cause life with the new gadgets to be perceived as rather more frustrating instead of enriching.

\textit{Casual Interaction} can improve the relationship between users and devices. Limiting the required focus for a task to a suitable minimum and designing the interactions in a way that the user can decide how much effort she wants to put into it offers the flexibility needed in a life with the Internet of things. The concept is showcased in the following scenario in context of the \textit{Smart Home} and ambient light control.

\begin{quotation}
	Alice comes home from grocery shopping. While carrying her shopping to the kitchen, she quickly turns on the light by simply touching her bracelet.
	
	After storing everything, she decides to relax in the living room by reading a book. After turning the kitchen lights off by covering the bracelet with her hand, she makes herself at ease on the sofa and picks up the book. To feel more comfortable, Alice dims the living room light a little by covering the bracelet's touch surface and tilting her wrist, just as she was turning a dimmer knob. The living room lights dim accordingly, so she doesn't need to look any closer at the bracelet.
	
	Later that day, Alice prepares dinner and the dining table in the living room. She uses the bracelet's touch controls to specify the exact setup for each light in the room, picking exact colors by sliding and tapping on the bracelet. Alice saves three lighting setups together with unique activation gestures: A warm setting for their guests' arrival and enjoying the welcoming drinks, a well-matched dining setup with focus on the table and foods, and a darker, colorful mood for drinking cocktails after dinner. Changing between these presets with hand gestures allows Alice to focus on her guests and on the meal instead of wasting time and focus by fiddling with wall panels or switches.
	\end{quotation}
	
This scenario illustrates multiple levels of casual interaction with a device: A simple on/off function by covering the bracelet's touch surface does not need sight on the device or high precision, this task is easily accomplished even when the user is distracted or encumbered. Likewise eyes-free brightness dimming by covering the bracelet's capacitive surface and tilting the wrist is only slightly more complex, but this complexity is countered with increased intuition, since the interaction is closely related to the motion of turning a dimmer knob. Detailed color change by precise touch and a fine-tuned hue setup using focused touch interaction represents another level of complexity in which cognitive as well as physical attention is required. In addition, three hand gestures are available to easily access frequently used setups like bright white work light or slightly dimmed relaxing illumination.

In order to enable the interactions mentioned above, the device requires certain features. First, it should stay where it is needed without encumbering the user. Typical remotes or smartphones occupy at least one hand for every interaction they offer. This is not desired, so traditional hand-held devices do not fit the scenario presented above. Instead, there is the need for a wearable device that is attached to the body without getting in the way during everyday activities.

Second, touch-free interaction (i.e. control by gestures) should be possible to enable the above-described casual interaction scenarios. Capacitive touch input offers flexibility and versatility compared to traditional keypads and enables gesture touch input. In addition, the required hardware should be kept on a low cost level and encompass only needed components to keep energy consumption at a minimum, since every recharge procedure is cumbersome for the user.

A bracelet-type device can fulfill the requirements stated above. It is slim and doesn't encumber the user, it can be worn on the arm all day.

This thesis presents the conception, design, prototyping, manufacturing as well as programming of an interactive electronic bracelet for ambient light control in the \textit{Smart Home}. Pros and cons on different materials for wrist-worm wearables as well as a description of the incorporated electronic parts and an overview of the hardware prototyping process can be found in chapter \ref{chap:bracelet}. A short summary of an exemplary interactive light source is presented in chapter \ref{sec:lamp}, while chapter \ref{sec:interaction} focuses on casual interaction and the ways to interact with the bracelet in great detail as well as their technical implementations. Chapter \ref{chap:evaluation} summarizes the lessons learned in the process of designing and manufacturing the bracelet, as well as impressions perceived by potential users. The thesis closes with a conclusion and an outlook on possible future work in this field (cf. chapter \ref{chap:conclusion}).

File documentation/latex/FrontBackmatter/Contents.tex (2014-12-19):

%*******************************************************
% Table of Contents
%*******************************************************
%\phantomsection
\refstepcounter{dummy}
\pdfbookmark[1]{\contentsname}{tableofcontents}
\setcounter{tocdepth}{2} % <-- 2 includes up to subsections in the ToC
\setcounter{secnumdepth}{3} % <-- 3 numbers up to subsubsections
\manualmark
\markboth{\spacedlowsmallcaps{\contentsname}}{\spacedlowsmallcaps{\contentsname}}
\tableofcontents 
\automark[section]{chapter}
\renewcommand{\chaptermark}[1]{\markboth{\spacedlowsmallcaps{#1}}{\spacedlowsmallcaps{#1}}}
\renewcommand{\sectionmark}[1]{\markright{\thesection\enspace\spacedlowsmallcaps{#1}}}
%*******************************************************
% List of Figures and of the Tables
%*******************************************************
\clearpage

\begingroup 
    \let\clearpage\relax
    \let\cleardoublepage\relax
    \let\cleardoublepage\relax
    %*******************************************************
    % List of Figures
    %*******************************************************    
    %\phantomsection 
    \refstepcounter{dummy}
    %\addcontentsline{toc}{chapter}{\listfigurename}
    \pdfbookmark[1]{\listfigurename}{lof}
    \listoffigures

    \vspace*{8ex}

    %*******************************************************
    % List of Tables
    %*******************************************************
    %\phantomsection 
    \refstepcounter{dummy}
    %\addcontentsline{toc}{chapter}{\listtablename}
    \pdfbookmark[1]{\listtablename}{lot}
    \listoftables
        
    \vspace*{8ex}
%   \newpage
    
    %*******************************************************
    % List of Listings
    %*******************************************************      
	  %\phantomsection 
    \refstepcounter{dummy}
    %\addcontentsline{toc}{chapter}{\lstlistlistingname}
    \pdfbookmark[1]{\lstlistlistingname}{lol}
    \lstlistoflistings 

    \vspace*{8ex}
       
    %*******************************************************
    % Acronyms
    %*******************************************************
    %\phantomsection 
    \refstepcounter{dummy}
    \pdfbookmark[1]{Acronyms}{acronyms}
    \markboth{\spacedlowsmallcaps{Acronyms}}{\spacedlowsmallcaps{Acronyms}}
    \chapter*{Acronyms}
    \begin{acronym}[PWM]
    	\acro{CAD}{Computer-Aided Design}
    	\acro{GSS}{Golden Section Search}
    	\acro{HCI}{Human-Computer Interaction}
    	\acro{HSL}{Hue Saturation Lightness}
    	\acro{I$^2$C}{Inter-Integrated Circuit}
    	\acro{IR}{Infrared}
        \acro{LED}{Light Emitting Diode}
        \acro{MIT}{Massachusetts Institute of Technology}
        \acro{MSE}{Mean Square Error}
        \acro{PCB}{Printed Circuit Board}
        \acro{PWM}{Pulse-width Modulation}
        \acro{RGB}{Red-Green-Blue}
        \acro{SPP}{Serial Port Profile}
        \acro{STL}{Sterolithography}
        \acro{USB}{Universal Serial Bus}
    \end{acronym}                     
\endgroup

\cleardoublepage

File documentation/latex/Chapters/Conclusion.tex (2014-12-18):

\chapter{Conclusion and Future Work}

This thesis presents the conceptualization and realization of casual interaction with a smart bracelet coupled to an ambient light source. The whole design process, from interaction conceptualization, hardware and software design to fabrication of the electronic components and implementation of the algorithms is taken into account and presented in a comprehensive manner. The focus lies on the design of interactions with a bracelet, so that frequently used tasks pose the least amount of interruption and require the least amount of focus from the user.

First impressions of potential users were positive, however a proper user study is required to confirm the acceptance of the device and the ways a user can interact with it. A possible study design would center on keeping the user distracted with different tasks while request him or her to operate the bracelet.

Revising the bracelet's software is likely required before planning any further work. From the first informal evaluation, some improvements for the interaction design can be derived and implemented. The gesture recognition algorithm needs to be optimized for the processor and converted into integer arithmetic. In addition, the Bluetooth module needs some extra fine tuning to flawlessly work with the lamp. Features and optimizations like this often go beyond the scope of a strictly time-constrained thesis.

For the future, the bracelet can be evaluated in combination with several other devices. Music playback control is an example that easily comes to mind, for example. Since the hardware is designed very generic in terms of usage applications, a great part of the thesis is easily reusable. In addition, the whole design and manufacturing process was laid out in detail, so that future designers of wearable prototypes can benefit from the past experiences.

The insights gained from the interaction design can be applied to other wearable devices which are worn around the wrist. For example, a smart watch could implement the bracelet's functionalities if a touch sensing wristband was added to it. This way, the insights gained from this thesis could be easily applied to future research or product design.

%TODO final sentence?

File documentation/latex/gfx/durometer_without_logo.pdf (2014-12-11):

0 10 20 | 30 | 40 | 50 | 60 | 70 | 80 | 90 | 100
0 | 10 | 20 | 30 | 40 | 50 | 60 | 70 | 80 | 90 | 100
0 10 | 20 30 | 40 | 50 | 60 | 70 | 80 | 90 | 100
EXTRA SOFT | SOFT | MEDIUM
SOFT

MEDIUM
HARD | HARD | EXTRA HARD

SHORE 00

SHORE A

SHORE D


GEL SHOE
INSOLE


‘GUMMI’ JELLY
CANDY


RUBBER BAND | PENCIL ERASER | TIRE TREAD | SHOE HEEL | SHOPPING CART WHEEL

HARD HAT

# SHORE HARDNESS SCALES

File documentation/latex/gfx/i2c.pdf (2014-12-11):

SDA; SCL; MSB; ACK; 002aac861; START or repeated START condition; STOP or repeated START condition; acknowledgement signal from slave; byte complete, interrupt within slave; clock line held LOW while interrupts are serviced; acknowledgement; signal from receiver

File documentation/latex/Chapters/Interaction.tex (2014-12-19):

\chapter{Interaction}
\label{sec:interaction}
In order to satisfactorily interact with the device, depending on physical, mental or social distractions, the user should be able to use the bracelet in different ways. Tasks that occur frequently should be completed in a very casual way, because tasks with low cognitive requirements are most likely still possible to execute successfully while the user is distracted. Rather infrequent tasks are allowed to demand more of the user's attention and cognitive capacity. If they occur rarely, the dissatisfaction of a failed task because of insufficient focus is not as grave as it would be if the task was a frequent one and if it would thus fail often.

As introduced in section \ref{sec:intro}, the user should be able to turn the lights on or off with a minimum of engagement, so the task would still be possible while, for example, physical encumbrance hinders the user from performing more complex interactions. Also, the action should not require more effort than moving to the wall switch and pressing it. 

A similar amount of or only slightly increased complexity in interaction should be required for dimming the lights, because this is also a frequently used function in daily life. The analogy of turning a dimmer knob makes this interaction easy to associate with its function. Dimming should be performable while under some degree of distraction, for example while participating in a conversation. Since both hands and a focused rotational movement are needed, acceptable physical distractions quickly reach a tolerance limit.

More focus could be required for changing the color in a fuzzy way, according to the concept of \textit{mood} derived from color psychology, on a loose range from calming to stimulating. Since this function would probably not be used very often, an interaction which requires a glance on the device to locate the proper spot for touching is considered reasonable. 

Changing the exact appearance of the light in terms of color, brightness and saturation however requires concentration and focus on the task, therefore the associated interaction with the bracelet can demand more of the user's engagement. Picking a certain template of presets in light color and setting is also a rather complex cognitive task that would happen infrequently, so associating it with a focused interaction seems appropriate.

\begin{table}
	\myfloatalign
	%$\left \Downarrow 
	\begin{tabularx}{.95\textwidth}{cc}
		\toprule
		\tableheadline{Task} & \tableheadline{Associated Interaction}\\ 
		\midrule
		switching on/off & covering touch area\\
		adjusting brightness & covering touch area, twisting the wrist\\
		fuzzy mood change & touch on two specific segments\\
		precise color change & combination of touch, slide, tap\\
		picking preset template & double tap and hand gesture\\
		\bottomrule
	\end{tabularx}
	%\right \downarrow $
	\caption[Tasks and associated interactions with the bracelet]{Tasks and associated interactions with the bracelet, in ascending complexity of the interaction and decreasing occurrence of the task}  \label{tab:interaction}
\end{table}

Table \ref{tab:interaction} shows how different interactions correspond to the described tasks. The focus in matching them lies on the required amount of attention needed to successfully complete the interaction as well as on the cognitive load a certain interaction entails. 

Since switching the lights on or off occurs rather frequently, a very simple action was associated with it. Covering the whole touch area of the bracelet for a few moments will trigger the on or off function of the device. When twisting the hand while covering said area, the light dims accordingly (cf. figure \ref{fig:onoff}). 

More complex tasks have more intricate interactions associated with them, for changing the lighting \textit{mood} a precise touch on two neighboring segments of the touch surface is required. This demands either a precise knowledge of the bracelet's shape and the layout of its components, or a concentrated glance at the touch surface in order to choose the right segments. Figure \ref{fig:mood} depicts this interaction.

A precise adjustment of the light in terms of hue, saturation and brightness requires even more focus on the task, since not only the function itself requires some concentration, but also the execution of the associated action does (cf. figure \ref{fig:hslinteraction}). To activate this settings mode, a single segment needs to be pressed, then the three attributes are set by sliding along the touch surface and switching to the next one with a tap on the bracelet's back side. After the last tap, the device returns to its ``standard mode'' in which all described functions are available.

The interaction of drawing a gesture in the air to pick a preset template for the lights was ranked the most complex in table \ref{tab:interaction}, although the physical requirements are not as high as in the previously described task of changing the color. In this case, the cognitive requirement of correctly remembering a movement pattern's association to a certain light configuration is higher than the physical requirement to execute the gesture correctly. There are three preset gesture actions for setting a bright work atmosphere, a dimmed and warm-colored relaxing environment and a colorful lounge mood, respectively. Gesture recognition is triggered with a tap on the bracelet's back, as illustrated in figure \ref{fig:hslinteraction}.

In the following sections, the various interaction levels with the bracelet and their underlying algorithms will be described in detail.

\section{Pairing the Bracelet with a Light Source}
The bracelet's Bluetooth module automatically searches for nearby devices and connects to a range of matching IDs without any interaction or confirmation by the user. This can pose a security risk to spoofing a lamp device, but since no sensitive data is handled by either participant, the impact would rather be an annoying disturbance than a serious threat to privacy.

\section{Switching the Light Source on and off}
\label{sec:onoff}
Since turning the lights in a specific room on or off is a frequently used interaction, it should require little complexity in terms of cognitive as well as physical workload, i.e. a simple, easily memorable way of interaction is desired. For those reasons, simply covering the touch surface with the whole hand (cf. fig. \ref{fig:onoff}) and holding for approximately $1.5$ seconds will result in switching the lights on or off, depending on the current state. Within this constraint, there is a tolerance of one segment when checking if the whole touch surface is covered, so that covering six out of seven capacitive segments would still trigger this function.

\begin{figure}[bth]
	\myfloatalign
		
	\caption{Covering and holding the bracelet's touch surface for on/off switching or dimming} \label{fig:onoff}
\end{figure}

While the touch slider is covered, the hand must be held fairly steady in terms of rotation to correctly trigger the on/off function, because otherwise the dimming algorithm would trigger instead. See section \ref{sec:dimming} for a specification of the tolerated rotation when covering the touch area. If the light is switched off, the current color would be saved by the bracelet and restored on the next ``on'' command.

\section{Adjusting the Light Source's Brightness}
\label{sec:dimming}
Apart from switching the lights on or off, a change in brightness is the second most desired interaction in the smart lighting scenario. For example, the desire of watching TV in the living room benefits from a dimmed light setting. However, if the user fails to locate the remote control for the television, a quick dim interaction towards brighter light facilitates the search for the missing remote control. After the item is found, the brightness level of the room's lighting can easily be dimmed back to the desired setting.

The dimming interaction is different from the other use cases, since there exists a physical solution for this task in form of dim knobs for wall outlets. Usually, those wall dimmers are rotary knobs connected to a potentiometer which dims the light source by increasing the electric resistance. Hence, the interaction of turning a knob for dimming the light level is an association for many people.

The intention was to preserve this association to make the interaction with the bracelet more intuitive. The dimming interaction is a combination of twisting the wrist while covering the bracelet's touch surface, imitating the interaction with the wall dimmer. The cover check routine is the same as described in section \ref{sec:onoff}, so covering six of the seven segments suffices to activate this function. While the touch surface is covered, the angle of the wrist rotation is constantly measured. From the way the accelerometer is mounted on the bracelet, the relevant axis for rotation is the Y-axis in the accelerometer's coordinate system. The following formula derives an angle $\alpha$ from the acceleration data \cite{Abayarjoo2013}:
\[ 
\alpha = tan^{-1}\left(\frac{y}{\sqrt{x^2 + z^2}}\right).
\]
Note that the accelerometer data must not include a gravity offset. If the observed angle exceeds certain thresholds and the current angle is at least $0.5\degree$ different from the previously measured value, a dimming step is executed and the brightness of all three color channels is reduced or increased by 10 percent. A counterclockwise movement (from the user's point of view) reduces the brightness, while a clockwise twist increases the brightness.

\section{Changing the Lighting Mood}
In addition to changing the brightness, the user should be able to adjust the light's color in a casual way and without thinking too much about the desired color in detail. Hence, the user is able to change the \textit{mood} of the light by touching two neighboring segments of the bracelet's touch element. Activating the left pair of segments increases the blue channel by one percent every $10$ ms while decreasing the red channel by one percent every $10$ ms; a touch on the right pair of segments causes the opposite (cf. fig. \ref{fig:mood}). Since blue colors are perceived as calming and relaxing while reds and oranges have an activating and stimulating effect \cite{Rosenstein1985}, this function can actually affect the user's mood by utilizing insights of color psychology.

\begin{figure}[bth]
	\myfloatalign
	\subfloat[Coodling down the light \textit{mood} by increasing the blue channel]
	{} \quad
	\subfloat[Warming up the light \textit{mood} by increasing the red channel]
	{}
	\caption{Touch interaction for \textit{mood} change} \label{fig:mood}
\end{figure}

\section{Precise Touch Input for Color Change}
Since adjusting the light color in a rather fuzzy way as described in the previous section is sometimes too imprecise, an additional function for setting the exact light color has been implemented. The RGB color model used by the lamp (cf. chapter \ref{sec:lamp}) is not very intuitive to the average user in terms of expressing a specific color in fractions of red, green and blue light, respectively, so the \ac{HSL} color model was used instead for this interaction.

\begin{figure}[bth]
	\myfloatalign
	\subfloat[The RGB color model, represented as a cube]
	{} \quad
	\subfloat[The \ac{HSL} color model, represented as a cylinder]
	{}
	\caption[Comparison of the RGB and \ac{HSL} color models]{Comparison of the RGB and \ac{HSL} color models, CC-BY-SA Michael Horvath} \label{fig:color}
\end{figure}

While the \ac{RGB} color space forms a cube with red, green and blue channel on each axis, the \ac{HSL} color space forms a cylinder. Hue represents the angle, while saturation stands for the diameter and lightness for the cylinder's height. Figure \ref{fig:color} illustrates that difference. Since the conversion from \ac{HSL} to RGB color space is not trivial, a conversion algorithm had to be implemented (\cite{qwertie}, derived from \cite{graphicsgems}). For given hue $H\in \left[ 0\degree , 360\degree \right]$, saturation $S\in \left[ 0, 1\right]$ and lightness $L\in \left[ 0, 1\right]$, the chroma value $C$ is calculated first:
\[
C = \left( 1 - \left| 2L-1\right| \right) \times S
\]
An intermediate value $X$ is calculated, and, depending on the value of $H$, the values for red, green and blue can be determined.
\[
X = C\left( 1 - \frac{H}{60\degree} \mod{2} - 1\right)
\]
\[
\left(R, G, B\right) = \left(m, m, m\right) + 
\begin{cases}
(0, 0, 0) &\mbox{if } H \mbox{ is undefined} \\
(C, X, 0) &\mbox{if } 0 \leq \frac{H}{60\degree} < 1 \\
(X, C, 0) &\mbox{if } 1 \leq \frac{H}{60\degree} < 2 \\
(0, C, X) &\mbox{if } 2 \leq \frac{H}{60\degree} < 3 \\
(0, X, C) &\mbox{if } 3 \leq \frac{H}{60\degree} < 4 \\
(X, 0, C) &\mbox{if } 4 \leq \frac{H}{60\degree} < 5 \\
(C, 0, X) &\mbox{if } 5 \leq \frac{H}{60\degree} < 6
\end{cases}
\]
Where $m$ denotes a lightness offset to the color:
\[
m = L - \frac{C}{2}
\]

A contact on the middle segment of the capacitive touch strip, held for approximately $100$ milliseconds activates this mode. The touch strip becomes a touch slider for changing the hue, while the saturation value is preset to its maximum value and lightness is set to half the maximum value. This makes the hue bright and saturated, so the user can focus on choosing the desired color. When the hue is set, a tap on the bracelet's back switches to the next component setting, namely saturation (cf. fig. \ref{fig:hslinteraction}). Tapping instead of touching somewhere on the touch surface ensures that the chosen color would not be offset by any accidental contact while trying to confirm the current selection. The bracelet's \ac{LED} acknowledges a tap with a green blink and the next parameter can be set. After setting the lightness, a tap on the backside brings the bracelet back into its standard mode, where all commands listed in this chapter are available again. During the precise color change command, the action cannot be aborted. Instead, the user needs to quickly cycle through the settings in order to leave this mode.

\begin{figure}[bth]
	\myfloatalign
	\subfloat[Activation of the color choosing mode by touching the middle segment]
	{} \quad
	\subfloat[Tapping on the bracelet's back side to switch to the next parameter]
	{}
	\caption{Interaction with the bracelet to precisely set the color} \label{fig:hslinteraction}
\end{figure}

\section{Template picking by Gesture Recognition}
The last form of interaction with the bracelet is by drawing gestures in the air to trigger preset color and brightness configurations. A ``Z''-shaped gesture changes the light color to a bright white which is ideal for working, e.g. while preparing a meal in the kitchen or cleaning the house. The second gesture is a circle drawn in the air, which switches to a soft, warm-colored and slightly dimmed setting which is suitable for relaxing activities like reading or watching TV. The third gesture is a pigtail-like looping which triggers a colorful, dark purple, lounge-like setting. The gestures are depicted in table \ref{tab:colors}, where also the exact values for the red, green and blue channels of the lamp are listed.

\begin{table}
	%\newcolumntype{C}{>{\centering\arraybackslash}c}
	\myfloatalign
	\begin{tabularx}{0.9\textwidth}{cccccc}%{CCCCCC}
		\toprule
		\tableheadline{Gesture} & \tableheadline{Name} & \tableheadline{Association} & \tableheadline{Red} & \tableheadline{Green} & \tableheadline{Blue}\\ 
		\midrule
		 & Z & Work & $ 255 $ & $ 255 $ & $ 255 $\\
		 & Circle & Relax & $255$ & $50$ & $0$\\
		 & Pigtail & Lounge & $150$ & $0$ & $50$\\
		\bottomrule
	\end{tabularx}
	\caption[Color presets for gesture activation]{Color presets and associations for gesture activation}  \label{tab:colors}
\end{table}

These gestures are recorded by the bracelet's accelerometer and processed using the ``3\$ Gesture Recognizer'' \cite{Kratz2010}, an extension of the popular ``1\$ Recognizer'' by Wobbrock et. al \cite{Wobbrock2007}. The algorithm is explained in detail in the following paragraphs.

Gesture recognition is triggered by double tapping on the bracelet's back side (for a more detailed specification of the tap recognition, see section \ref{sec:config}). This focused activation was chosen to prevent accidental triggering of the gesture recognition procedure while gesturing heavily, e.g. during a conversation. A little more effort in starting this rather rarely used feature is preferred over a higher false positive rate in gesture recognition triggering. After a double tap was detected, the \ac{LED} indicates with a red glow that acceleration data is recorded while the next $150$ samples are saved for the gesture recognition algorithm.

Wobbrock as well as Kratz start their processing with a resampling step to compensate for different speeds in drawing the gesture. If the gesture was drawn quickly, it would have less samples and thus less points compared to a slowly drawn gesture. In order to be able to compare these two gestures, a resampling is performed before further processing. Therefore, the gesture is resampled to a fixed number of points before other processing takes place. Since the implementation in this thesis always records a fixed number of samples, this step is omitted. This can lead to cut off gestures when drawn too slowly or added noise at the end of a data set if the gesture was drawn too quickly. While recording test samples with various people, the record period however seemed appropriate for most gestures that were executed.

In the next step, the gesture is prepared for matching against the templates by rotating it to a specific position. The so called \textit{indicative angle} $\theta$ between the gesture's centroid $C$ and its first point of the data set is calculated using the normalized scalar product of the centroid and the first point's position vectors. Afterwards the gesture is rotated so that $\theta$ is at $0\degree$. Wobbrock et. al. do this by using the inverse tangents function, however this is not possible in 3D space. Hence, \textit{Rodrigues' rotation formula} (named after French mathematician Olinde Rodrigues) was implemented instead. This efficient algorithm for rotating a vector in $\mathbb{R}^3$ takes the rotation angle $\theta$ as well as the axis unit vector $k$ as input, and calculates the following formula:

\begin{center}
\(
v_{rot} = v \cos\theta + (k \times v)\sin\theta + k (k \cdot v) (1 - \cos\theta).
\) \cite{koks2006}
\end{center}

After applying this function on the gesture, a good starting point is created for the actual recognizing part of the algorithm. Listing \ref{lst:rotate2zero} illustrates the rotation procedure.

\begin{lstlisting}[label=lst:rotate2zero,language=python,frame=lt,caption=Rotation of points so that their indicative angle is at $0 \degree$]
def rotate_to_zero(points):
	c = centroid(points)
	theta = acos(points[0] * c / (|points[0]| * |c|)
	newpoints = rotate_by(points, -theta)
	return newpoints
\end{lstlisting}

In order to harmonize gestures of different sizes which represent slow or quick movements, the points are scaled to a reference cube with edge length of $100$ units and translated so that the respective centroid $C$ is on the origin (cf. listing \ref{lst:scale+translate}).

\begin{lstlisting}[label=lst:scale+translate,language=python,frame=lt,caption=Scaling to reference cube and translation to origin]
def scale_and_translate(points, size): # size=100
	B = Bounding_Box(points)
	newpoints = []
	for p in points:
		q = Point()
		q.x = (p.x * (size / B.width)) - c.x
		q.y = (p.y * (size / B.height)) - c.y
		q.z = (p.z * (size / B.depth)) - c.z
		newpoints.append(q)
	return newpoints
\end{lstlisting}

After these harmonization and preparation steps, the gestures are matched against the prerecorded templates (cf. listing \ref{lst:recognize}). The aforementioned steps are applied to templates as well as to newly recorded gestures, the following algorithms only apply to unrecognized gestures.

\begin{lstlisting}[label=lst:recognize,language=python,frame=lt,caption=Matching candidate gesture against every template]
def recognize(points, templates, rescale_size):
	theta_min = -180
	theta_max = 180
	theta_delta = 2

	best = float("inf")
	for t in templates:
		dist = distance_at_best_angle(points, t, theta_min, theta_max, theta_delta)
		if dist < best:
			best = dist
			t_best = t
	return t_best
\end{lstlisting}

The candidate is compared to all stored templates using the average \ac{MSE} as a scoring metric. The optimal position between the candidate gesture and a stored template is possibly offset by a certain rotation, so the optimal combination of angles between the two gestures needs to be determined. Since rotations are costly in terms of computation time, the candidate gesture should be aligned to the template in as few tries as possible. Hence, as proposed by \cite{Kratz2010}, a \ac{GSS} is used to find the optimal angles $\alpha$, $\beta$, and $\gamma$ for rotation around the three axis of the coordinate system.

The \ac{GSS} algorithm was invented by US-American statistician Jack Kiefer in 1953  and is conceptualized to find the minimum value $x^*$ of a unimodal function $f\left(x\right)$ in a given interval $\left[a,b\right]$ \cite{Kiefer1953}. Two function points $f(x_1)$ and $f(x_2)$ with 
\[ x_1=a+\left(1-\phi\right)\left(b-a\right) \\
x_2=a+\phi\left(b-a\right) \]
are calculated and compared, where 
\[\phi=\frac{2}{\left(1+\sqrt{5}\right)}\]
denotes the Golden Section constant. If $f\left(x_1\right) < f\left(x_2\right)$, the interval for the next iteration becomes $\left[a,x_1\right]$ and the new test points are calculated as described above with respect to the new interval borders. Note that the value $f\left(x_1\right)$ can be reused \cite{chang2009n}. If $f\left(x_1\right) > f\left(x_2\right)$, the interval for the next iteration step changes to $\left[x_2, b\right]$ respectively. If the function points differ not more than a given $x_\Delta$, the current minimum will be accepted as the algorithm's result.

In the context of the implemented gesture recognizer, the function to be minimized is the distance between a gesture candidate and a certain template at the best angle. Since the recognizer works with three-dimensional data, there is not a single angle for rotation, but one for each coordinate axis. Hence, the \ac{GSS} needs to be adapted for three dimensions.

As listing \ref{lst:daba} illustrates, the three-dimensional approach is similar to the one-dimensional algorithm. Each of the variables $\alpha$, $\beta$, $\gamma$ has its own search interval and a pair of calculated values. This leads to eight function points to be evaluated in each iteration, denoted in the code by variables \texttt{f1} to \texttt{f8}. The minimum of these values is calculated and the intervals adjusted accordingly. Note that in every case one function value from the previous step can be carried over, for example when \texttt{f1} is the minimum, its value is used for the new \texttt{f8}.

\begin{lstlisting}[label=lst:daba,language=python,frame=lt,caption=Three-dimensional Golden Section Search for finding the best angle between a candidate gesture and a template]
def distance_at_best_angle(p, t, theta_min, theta_max, theta_delta):
	phi = 0.5 * (-1 + math.sqrt(5))
	a_min = theta_min
	a_max = theta_max
	b_min = theta_min
	b_max = theta_max
	g_min = theta_min
	g_max = theta_max

	x1 = phi * a_min + (1 - phi) * a_max
	x2 = (1 - phi) * a_min + phi * a_max
	y1 = phi * b_min + (1 - phi) * b_max
	y2 = (1 - phi) * b_min + phi * b_max
	z1 = phi * g_min + (1 - phi) * g_max
	z2 = (1 - phi) * g_min + phi * g_max	

	f1 = distance_at_angle(p, t, x1, y1, z1)
	f2 = distance_at_angle(p, t, x1, y1, z2)
	f3 = distance_at_angle(p, t, x1, y2, z1)
	f4 = distance_at_angle(p, t, x1, y2, z2)
	f5 = distance_at_angle(p, t, x2, y1, z1)
	f6 = distance_at_angle(p, t, x2, y1, z2)
	f7 = distance_at_angle(p, t, x2, y2, z1)
	f8 = distance_at_angle(p, t, x2, y2, z2)

	while (|a_max - a_min| > theta_delta) or (|b_max - b_min| > theta_delta) or (|g_max - g_min| > theta_delta):	
		min_f = min(f1, f2, f3, f4, f5, f6, f7, f8)
		if min_f == f1: #x1, y1, z1
			a_max = x2
			x2 = x1
			x1 = phi * a_min + (1 - phi) * a_max
			b_max = y2
			y2 = y1
			y1 = phi * b_min + (1 - phi) * b_max
			g_max = z2
			z2 = z1
			z1 = phi * g_min + (1 - phi) * g_max
			f8 = f1
			f1 = distance_at_angle(p, t, x1, y1, z1)
			...
			f7 = distance_at_angle(p, t, x2, y2, z1)
		elif min_f == f2: #x1, y1, z2
			...
		else: #x2, y2, z2
			...
	return min(f1, f2, f3, f4, f5, f6, f7, f8)
\end{lstlisting}

To determine the distance between a gesture and a certain template at given angles $\alpha$, $\beta$, and $\gamma$, the gesture is rotated using the Rodrigues rotation formula discussed in the context of the indicative angle above. The rotation formula needs an axis and an angle for executing the rotation, but the \ac{GSS} works with three angles. Therefore, the rotation matrix formed by the angles needs to be transformed into a Euler axis and angle pair for use in the implemented rotation formula. The authors of \cite{Kratz2010} state the following rotation matrix in their reference implementation \cite{repo:3dollar}:
%TODO explain euler axis/angle?
\[
A = 
\begin{pmatrix}
\cos{\alpha}\cos{\beta} & \cos{\alpha}\sin{\beta}\sin{\gamma} - \sin{\alpha}\cos{\gamma} & \cos{\alpha}\sin{\beta}\cos{\gamma} + \sin{\alpha}\sin{\gamma} \\
\sin{\alpha}\cos{\beta} & \sin{\alpha}\sin{\beta}\sin{\gamma} + \cos{\alpha}\cos{\gamma} & \sin{\alpha}\sin{\beta}\cos{\gamma} - \cos{\alpha}\sin{\gamma} \\
-\sin{\beta} & \cos{\beta}\sin{\gamma} & \cos{\beta}\cos{\gamma}
\end{pmatrix}
\]

The Euler rotation angle $ \theta $ is composed by the matrix's diagonal elements.
\begin{eqnarray*}
\theta & = & \arccos\left(\frac{1}{2}\left(A_{11} + A_{22} + A_{33} - 1\right)\right) \\
       & = & \arccos\left(\frac{1}{2}\left(\cos\alpha\cos\beta+\sin\alpha\sin\beta\sin\gamma+\cos\alpha\cos\gamma+\cos\beta\cos\gamma-1\right)\right)
\end{eqnarray*}
The rotation axis vector $ e $ can be derived from $ A $ and $ \theta $ as follows:
\begin{eqnarray*}
e_1 & = &  \frac{A_{32} - A_{23}}{2\sin\theta} \\
    & = & \frac{\sin\alpha\sin\beta\cos\gamma-\cos\alpha\sin\gamma-\cos\beta\sin\gamma}{2\sin\theta} \\
e_2 & = & \frac{A_{13} - A_{31}}{2\sin\theta} \\
    & = & \frac{-\sin\beta-\cos\alpha\sin\beta\cos\gamma-\sin\alpha\sin\gamma}{2\sin\theta} \\
e_3 & = & \frac{A_{21} - A_{12}}{2\sin\theta} \\
    & = & \frac{\cos\alpha\sin\beta\sin\gamma-\sin\alpha\cos\gamma-\sin\alpha\cos\beta}{2\sin\theta}
\end{eqnarray*}

And like this, the angles determined in algorithm \ref{lst:daba} lead to an axis/angle rotation which is performed on the candidate gesture.

Once the best template for a candidate gesture is found, the corresponding index in the stored template list is returned and the recognized gesture triggers certain changes in the light source's color or brightness. Note that this gesture recognition algorithm is only used for recognition of the preset gestures formulated at the beginning of this section.

\section{Presets and Configuration}
\label{sec:config}
Gesture recording and recognition is triggered by a gentle double tap on the bracelet. This small but focused activation reduces unwanted triggering of the gesture recognition process, e.g. while gesturing heavily, and thus reducing false positives. The tap detection functionality is a built-in feature of the bracelet's accelerometer, configuration parameters for this process are listed in table \ref{tab:tapconf}.

In order to be recognized as a tap interaction, the initial impulse needs to be at least $6.3$ g in intensity. When calibrated like this, jerky movements like suddenly raising the hand at a high speed are correctly not recognized as a tap. However since the threshold is that high, the activation tap needs to be executed directly on the hardware which is located on the inner wrist.

The \texttt{PULSE\_TMLT} register configures the maximum time interval between the  impulse exceeding the threshold on the Z axis and falling back under said threshold. If the mentioned interval lasts at most $6.25 ms$, the interaction is considered as a tap.

After a tap is detected, all impulses in the following $25ms$ are ignored by the detection mechanism. This prevents bouncing effects and detecting multiple taps in a singe tap movement.

The MMA8652FC accelerometer is able to distinguish between single and double taps. The last configuration register listed in table \ref{tab:tapconf} is a parameter for double tap detection. It specifies the maximum time interval between two double taps and is set to $500 ms$, the same time interval as the Microsoft Windows default between two mouse clicks of a double click \cite{doubleclick}.

\begin{table}
	\myfloatalign
	\begin{tabularx}{\textwidth}{lll} \toprule
		\tableheadline{Register Name} & \tableheadline{Parameter} & \tableheadline{Value}\\ 
		\midrule
		\texttt{PULSE\_THSZ} & Tap Detection Threshold & $6.3$ g\\ 
		\texttt{PULSE\_TMLT }& Interval between Start and End Pulse & $6.25$ ms\\
		\texttt{PULSE\_LTCY} & Ignore Interval after Detection & $25$ ms\\
		\texttt{PULSE\_WIND} & Maximum Double Tap Interval & $500$ ms \\
		\bottomrule
	\end{tabularx}
	\caption[Tap detection configuration]{Single- and double tap detection configuration for the MMA8652FC digital accelerometer}  \label{tab:tapconf}
\end{table}

Apart from accelerometer calibration, the gesture recognition algorithms needs template gestures, against which the interactively recorded data is matched. Wobbrock et. al. as well as Kratzand Rohs most likely use artificially constructed templates, though neither of them explicitly states this in their work \cite{Wobbrock2007} \cite{Kratz2010}. Constructing artificial templates for 2D stylus-based input is very easy, since the stylus produces a series of lines, rather independently from the used speed or size. When working with accelerometer data however, the recorded data is more heterogeneous, since quickly drawn gestures result in higher amplitudes in the raw data. Since it is very difficult to find the right speed and size to artificially construct template gestures, an empirical approach was used.

Ten gesture executions of each type (Z, circle, and pigtail) were performed by eight people. Then, one gesture after another was examined as a template and statistics for correct matches as well as false positive matches were recorded. Since gestures with the least false positive rate also share very low matching rates, a ratio of
\[
\frac{\text{\# correct matches}}{\text{\# false positives}}
\]
was calculated to determine the most representative gestures. The best N gestures according to said metric were chosen as templates for the live gesture detection.

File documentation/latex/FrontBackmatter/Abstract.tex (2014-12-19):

%*******************************************************
% Abstract
%*******************************************************
%\renewcommand{\abstractname}{Abstract}
\pdfbookmark[1]{Abstract}{Abstract}
\begingroup
\let\clearpage\relax
\let\cleardoublepage\relax
\let\cleardoublepage\relax

\chapter*{Abstract}
In this thesis, a casual interaction scenario in context of the \textit{smart home} is presented. Based on this scenario, an interactive wearable bracelet for ambient light control was designed and implemented in terms of physical hardware, electronic components, interaction design and software. Users are able to interact with the device in various ways that demand different amounts of focus and cognitive load, so that interaction can successfully take place even when the user is encumbered or distracted by various physical, mental or social aspects of daily life.

\vfill

\pdfbookmark[1]{Zusammenfassung}{Zusammenfassung}
\chapter*{Zusammenfassung}
In dieser Arbeit wird ein Szenario f\"ur beil\"aufige Interaction im Kontext eines \textit{Smart Home}. Darauf aufbauend wurde ein interaktives elektronisches Armband f\"ur die Steuerung einer Lam\-pe realisiert. Der Design- und Herstellungsprozess umfasste alle Bereiche des Ger\"ates, vom Armband selbst \"uber die verbaute Hardware, die Interaktionsgestaltung bis hin zur Software. Die Benutzer k\"onnen auf verschiedene Arten mit dem Ger\"at interagieren, die unterschiedlich viel Aufmerksamkeit und geistige Leistung erfordern. So k\"onnen die Benutzer auch dann erfolgreich mit dem Ger\"at interagieren, wenn sie von ihrer Umgebung durch physische, mentale oder soziale Aspekte des t\"aglich\-en Lebens abgelenkt sind.

\endgroup			

\vfill

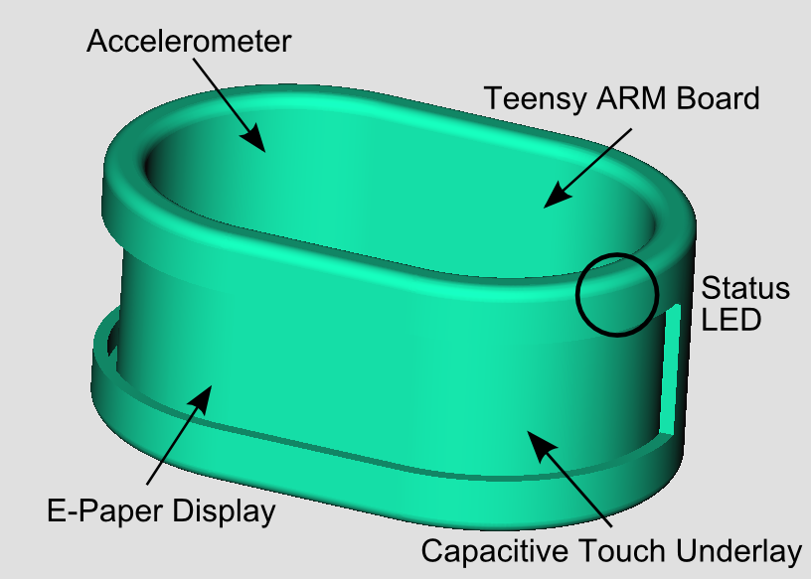
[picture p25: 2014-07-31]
documentation/slides kick-off/drawing.png

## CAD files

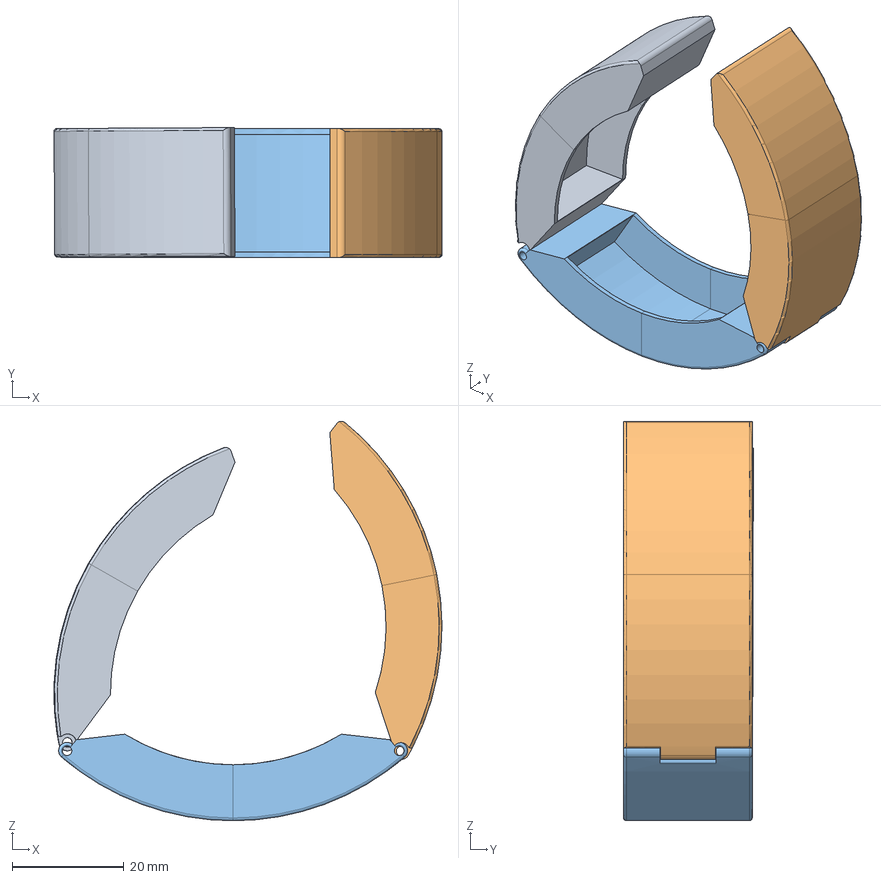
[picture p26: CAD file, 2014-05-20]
prints/04_tri_part_assembly.FCStd
69.3 x 23.2 x 71.4 mm
end 1
end 2
middle

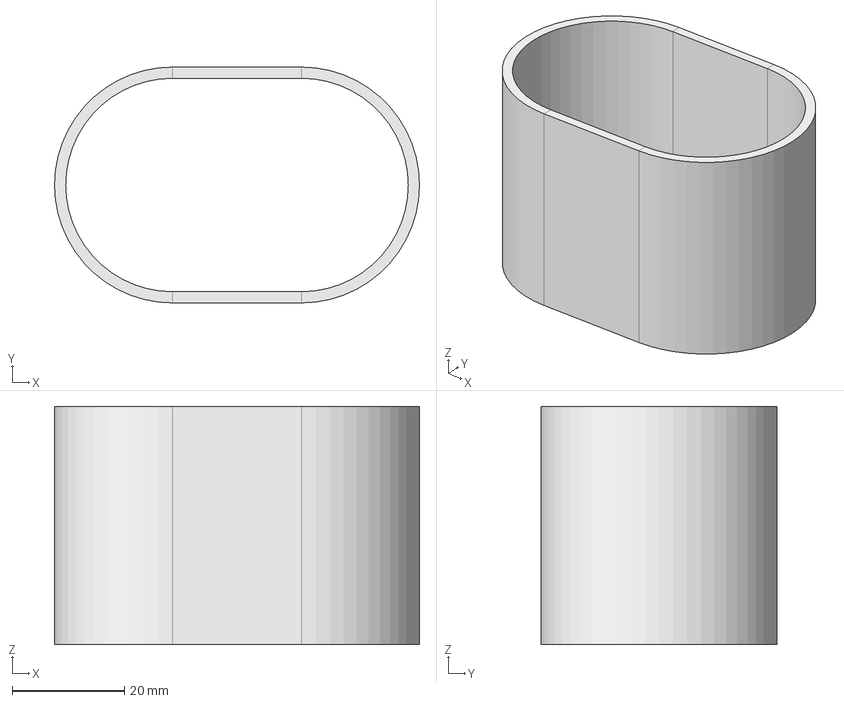
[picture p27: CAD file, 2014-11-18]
prints/08_inner_mold.FCStd
65.0 x 42.0 x 42.4 mm

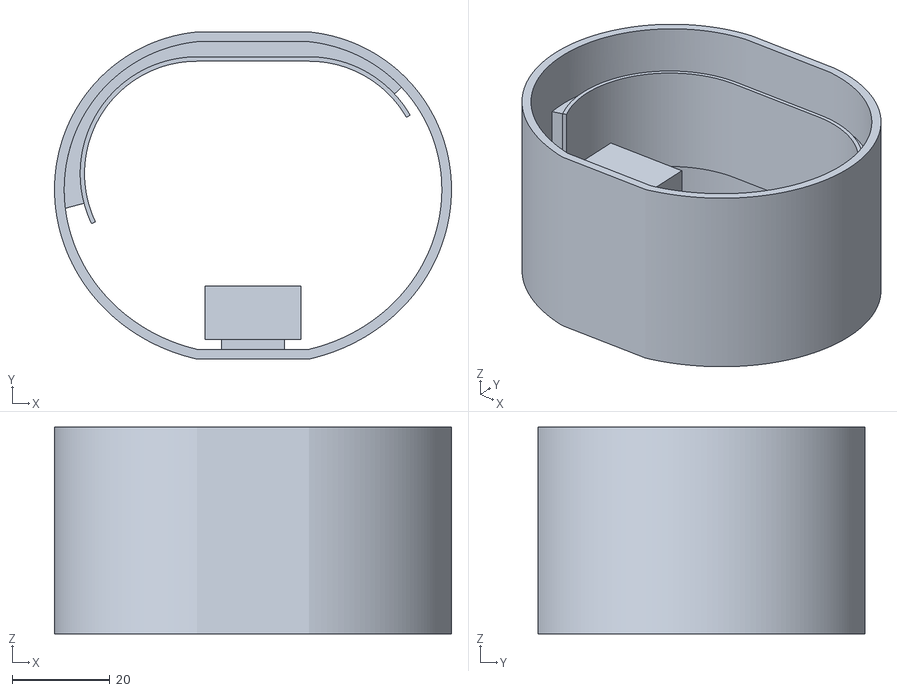
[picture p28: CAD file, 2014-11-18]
prints/08_outer.stl
81.3 x 67.0 x 42.4

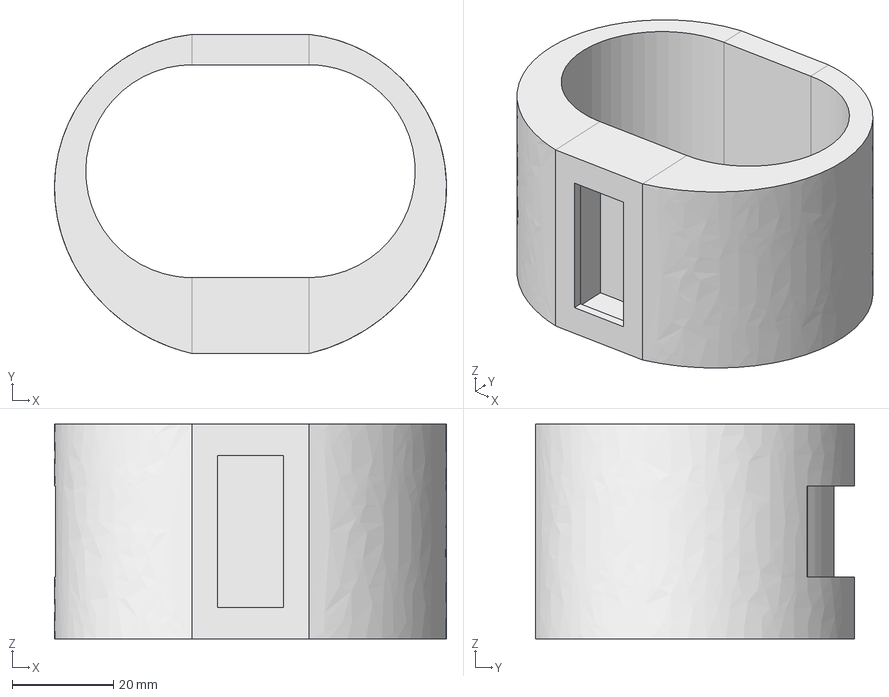
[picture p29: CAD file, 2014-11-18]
prints/08_outer_mold.FCStd
77.3 x 63.0 x 42.4 mm

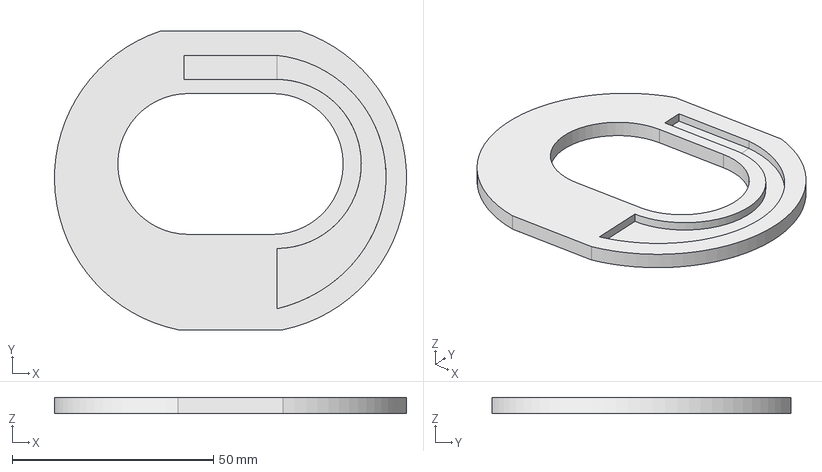
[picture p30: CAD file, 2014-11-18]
prints/08_base.FCStd
87.5 x 74.2 x 4.00 mm

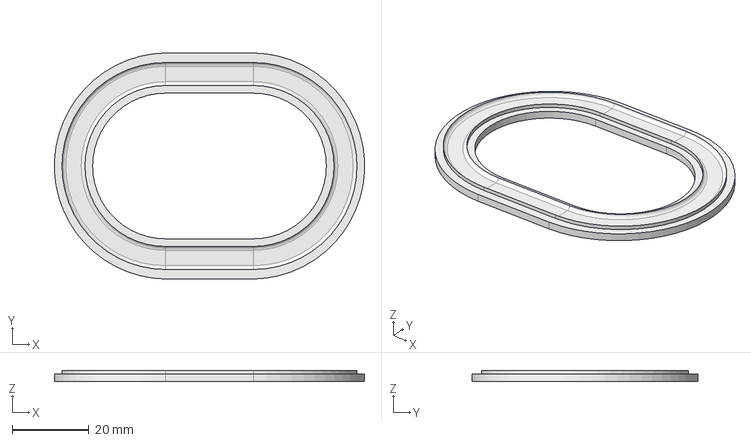
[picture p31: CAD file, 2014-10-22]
prints/07_base_mold.FCStd
80.9 x 59.0 x 3.00 mm

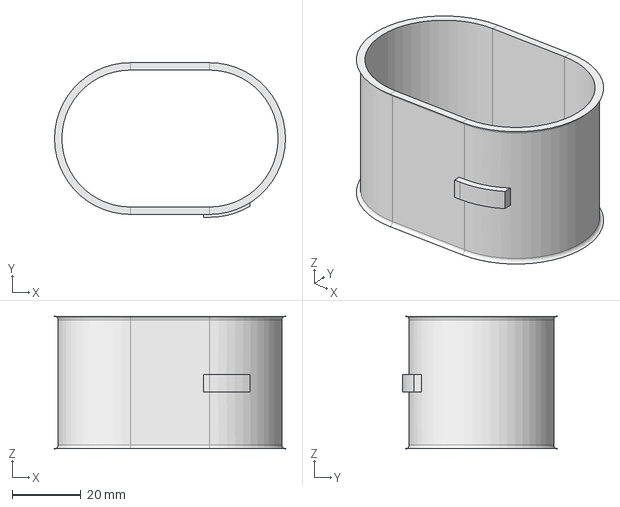
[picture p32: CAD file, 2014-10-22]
prints/07_inner_mold.FCStd
67.0 x 44.8 x 38.4 mm

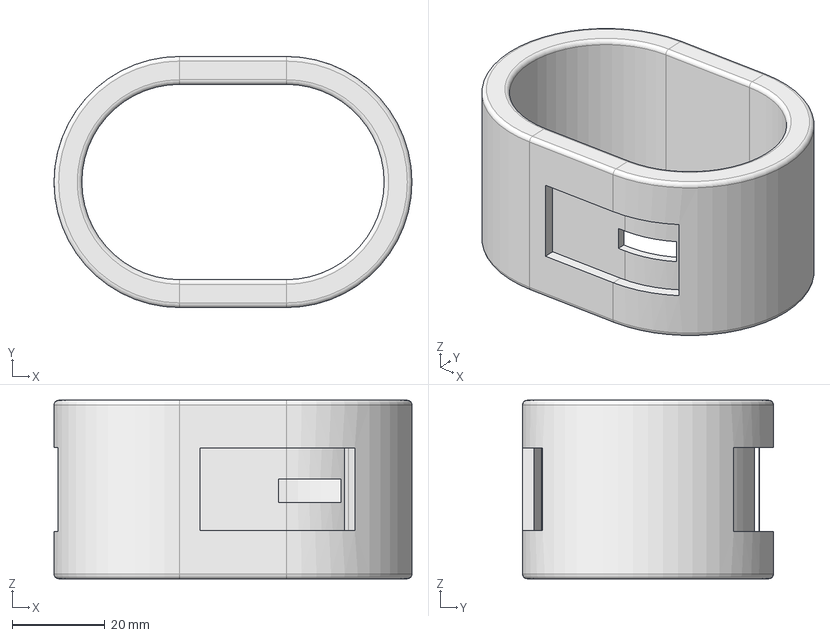
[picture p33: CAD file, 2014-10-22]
prints/07_bracelet_positivr.FCStd
77.0 x 54.0 x 38.4 mm

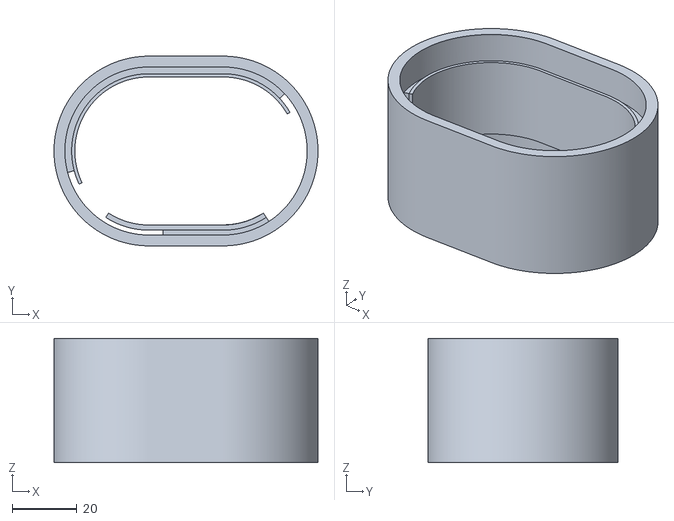
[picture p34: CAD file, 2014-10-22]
prints/07_outer_mold_blender_export.stl
81.7 x 58.7 x 38.4

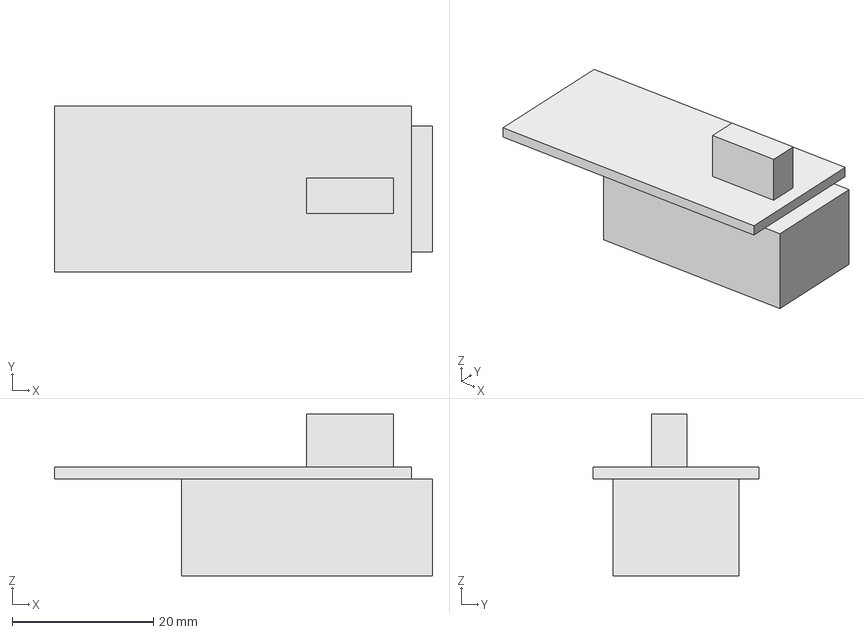
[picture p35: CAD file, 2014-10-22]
prints/07_teensy_with_board.FCStd
53.5 x 23.5 x 22.9 mm

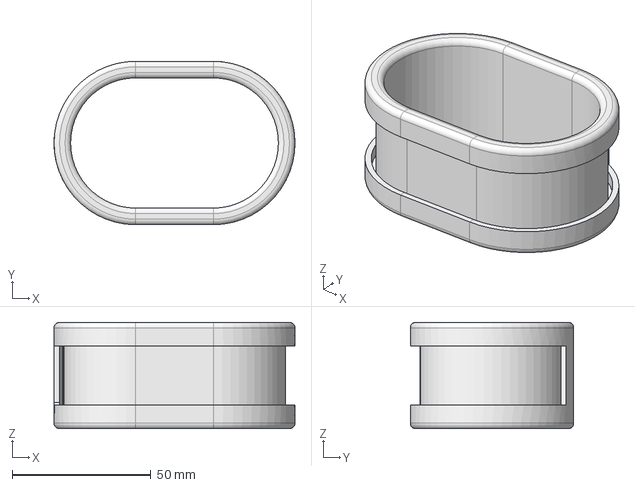
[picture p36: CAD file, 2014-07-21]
prints/06a_mold2_improved.FCStd
87.0 x 59.0 x 38.4 mm

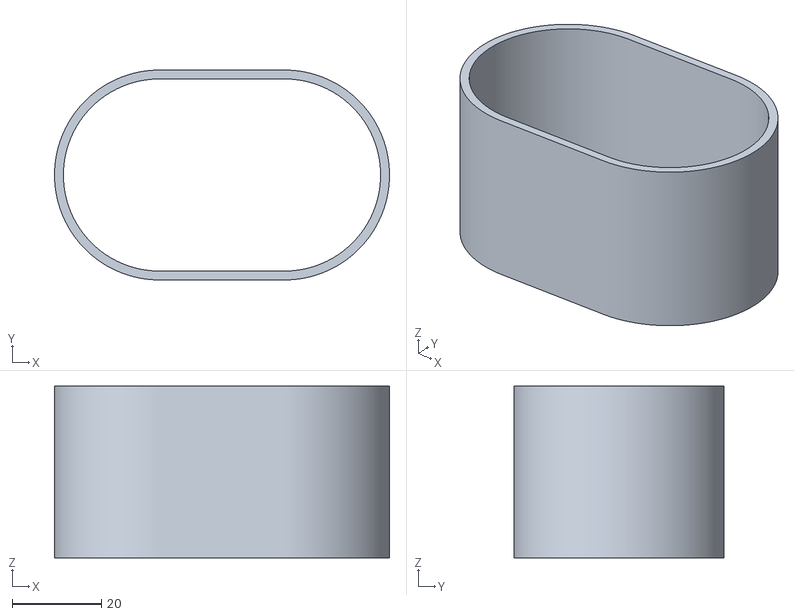
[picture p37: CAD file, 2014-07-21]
prints/06a_inner.stl
75.0 x 47.0 x 38.5

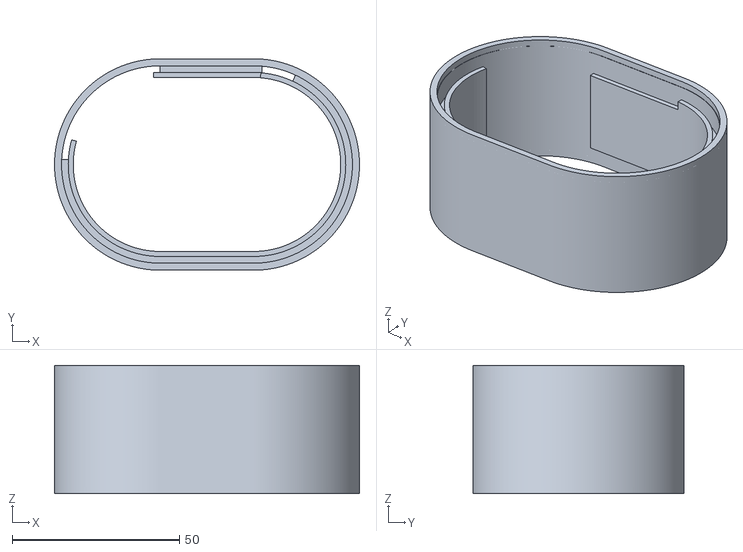
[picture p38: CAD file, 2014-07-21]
prints/06a_outer.stl
91.2 x 63.2 x 38.4

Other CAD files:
prints/08_outer_experimental.FCStd
prints/08_inner.stl
prints/08_teensy_with_small_board.FCStd
prints/07_outer_mold.FCStd
prints/06a_mold2_improved_outer.FCStd
prints/01_simple_cuff.FCStd
prints/01_simple_cuff.stl
prints/01_simple_cuff_no_fillets.stl
prints/02_comfortable_cuff.FCStd
prints/02_comfortable_cuff.stl
prints/02a_confortable_cuff_improved.FCStd
prints/02a_confortable_cuff_improved.stl
prints/02a_lid.FCStd
prints/02a_lid.stl
prints/03_amico_bracelet.stl
prints/03_amico_front.stl
prints/03_amico_side.stl
prints/04_tri_part_end.FCStd
prints/04_tri_part_end.stl
prints/04_tri_part_middle.FCStd
prints/04_tri_part_middle.stl
prints/04a_tri_part_middle.FCStd
prints/04b_tri_part_end.FCStd
prints/04b_tri_part_end.stl
prints/04b_tri_part_middle.FCStd
prints/04b_tri_part_middle.stl
prints/05_silicone_bracelet_mold.FCStd
prints/05_silicone_bracelet_moldable.FCStd
prints/06_mold2.FCStd
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

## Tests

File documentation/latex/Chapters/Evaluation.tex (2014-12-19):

\chapter{Evaluation}
\label{chap:evaluation}
\section{Impressions of the Device and its Interactivity}
Instead of a classical user study, the setup of interactive bracelet and lamp was presented to three participants in an informal structured interview. At first, the concept of casual interaction was explained to the participants and they were encouraged to reflect on the concept and think about interaction design for the scenario. Afterwards, the developed bracelet and its interaction was presented to the participants. There was no task to be completed, instead the users' approach towards the new device was observed. All participants were male Computer Science students.

Users found interacting with the bracelet enjoyable and quickly learned the basic functionality. Especially the hue slider during the precise color input was fascinating to the participants and they enjoyed playing with that feature. However, the function often triggered accidentally while using the bracelet. The gesture input was also enjoyed by the participants.

Tapping on the back of the bracelet to trigger certain functions was slightly misunderstood by some users. They didn't find the exact spot to tap on or tapped too gently on the device. This always resulted in a misconception about the device and the fact that the taps are triggered by an accelerometer instead of a touch surface. After explaining the concept to them, they succeeded better. An improved and optimized configuration for the tap detection settings (cf. section \ref{sec:config}) could eliminate this problem if it succeeds to increase the tap sensitivity while maintaining the low rate of unintended activation through other interactions.

After the interview, the participants were asked to anonymously rate the overall experience with the device and its interactions on a five-point Scale from ``not good at all'' (1) to ``very good'' (5). All people rated the experience with 4.

\section{Lessons Learned}
When designing a wearable electronic device for the wrist, the most important thing is to create an appealing shape and texture, so the user would have no problems in wearing the device for a longer time. Printed material has a rough texture that is uncomfortable to the skin and can even cause skin irritations if it scrubs for a longer amount of time. Cast silicone is much more skin friendly, and in addition it is a flexible material which allows for mounting parts without the need for additional adhesives, since simply adding pockets that hold the parts in under little to medium tension is often the best solution.

However, when the use of adhesives is not avoidable by any means, cast silicone is a very tricky material. Liquid glue and adhesive tape do not hold reliably, especially when the part to be attached would be under frequent tension. Hence, designing the wearable to be manufactured with only one cast is very desirable. This should be especially taken into consideration when designing closing mechanisms for silicone wearables.

While designing the electronic components, saving space has high priority. This inevitably leads to choosing surface mounted components. Some of those small packages are still possible to solder by hand, but very small packages for integrated circuits like the accelerometer used in this thesis usually lead to the need of a reflow soldering process. If there is no such equipment available, the use of very small components should be limited, since ordering populated boards at a factory usually takes a couple of days for them to arrive. The same holds for prototype \ac{PCB}s: Parts with small footprints lead to small lines on the board. It was perceived that the ability to mask and etch prototype boards featuring small footprints and thin lines somehow correlates with the ability to solder the respective components manually.

Choosing small sized parts leads to less required \ac{PCB} space. However, the components still need to be routed, which becomes more complicated when the board space shrinks and eventually leads to the need for double-layered \ac{PCB}s. Those, however, are complicated to fabricate with the low-cost masking and etching process, they either require advanced equipment like a CNC mill, or the involvement of a fabrication service. This needs to be considered when deciding for a double-layered \ac{PCB}.

Embedded prototyping boards like the Arduino device family or the Teensy board can be easily extended by stacking custom extension boards on top of them. As convenient as this may seems, it should be taken into account that extension boards are usually connected to standard spaced pin headers, which introduce extra height to the electronics piece that feels very bulky when attached to a wrist. A workaround to this problem was soldering an IC socket on the Teensy board instead of standard pin headers to save one or two millimeters in component height. The extension board featured manually shortened pin connectors. Such a setup should only be considered for the final iteration of the hardware, since the combination is hard to disassemble once the extension board has been firmly pressed into the socket. Even with this workaround, the board still feels a little clumsy and requires careful design of the casing.

When implementing code on an embedded platform, the processor's architecture should be taken into consideration, especially when a computation-intensive algorithm is planned to run on the device. The Teensy's processor did not have a floating point computing unit, so implementing the gesture recognition algorithm which relies heavily on trigonometry would have needed extensive modifications like using precalculated tables for trigonometric functions. Since those adjustments would have exceeded the given time frame for this thesis, the gesture recognition code was outsourced to a stationary PC to which the bracelet is connected for power supply.

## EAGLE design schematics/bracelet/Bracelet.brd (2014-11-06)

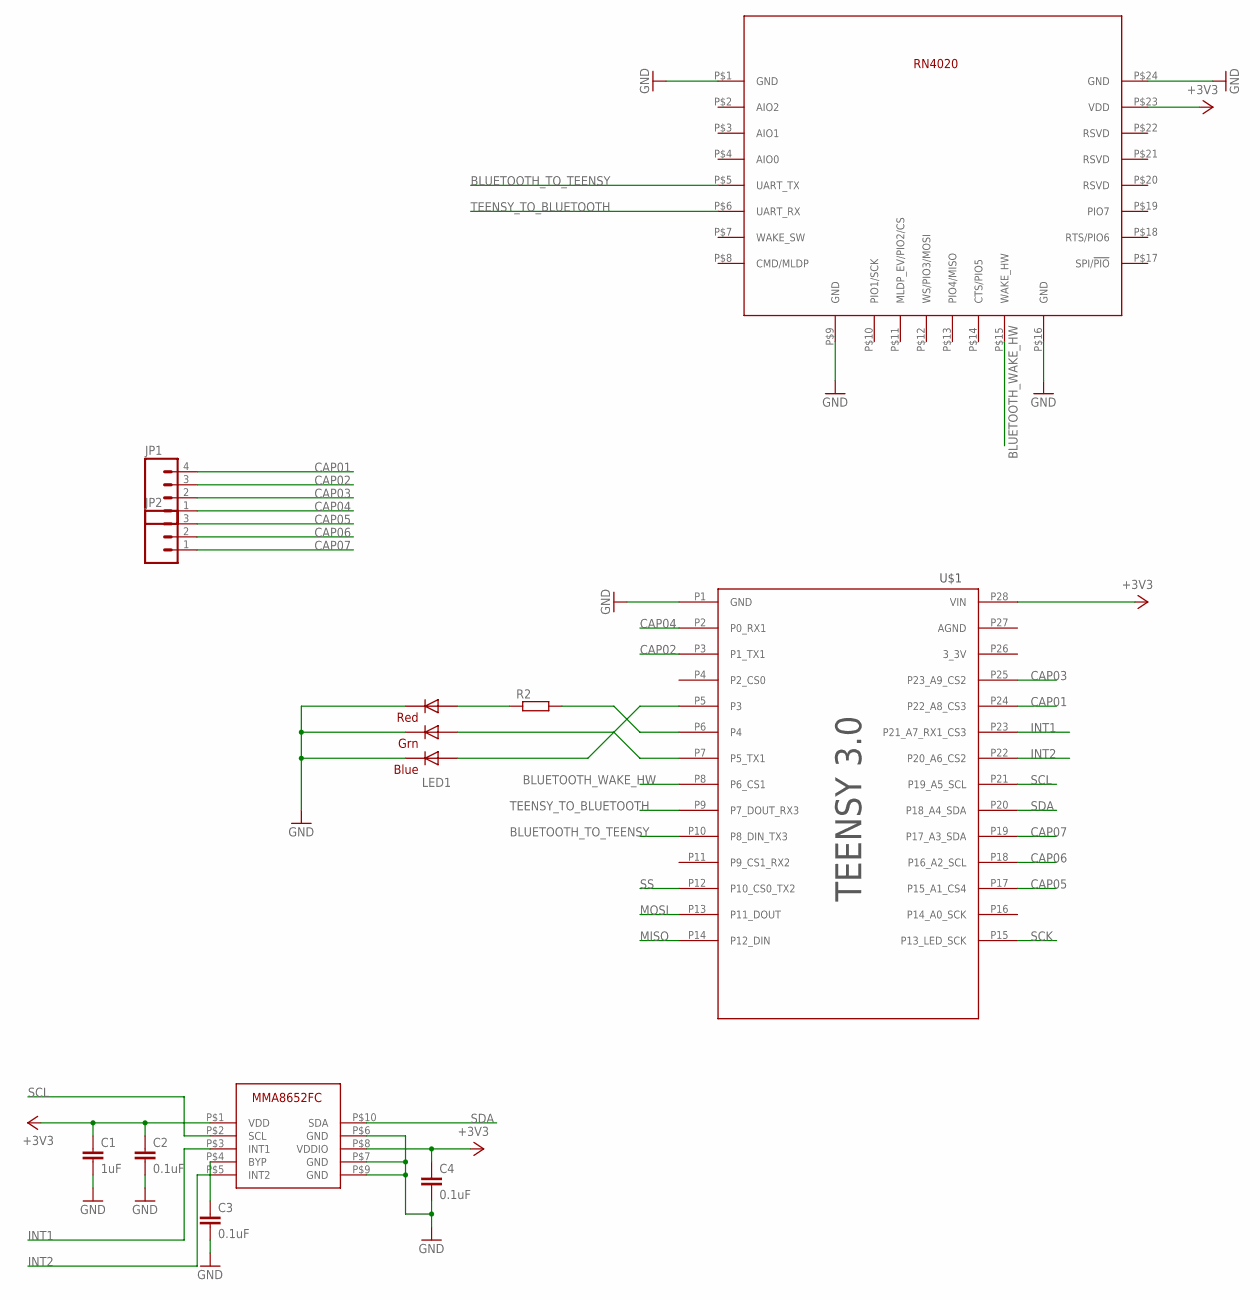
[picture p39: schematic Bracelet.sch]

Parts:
C1: 1uF; C0805
C2, C3, C4: 0.1uF; C0805
JP1: M04PTH; 1X04
JP2: M03PTH; 1X03
LED1: RGBLED5050
R2: R-EU_R0805; R0805
RN4020: RN4020
U$1: TEENSY3; TEENSY3_BRD
U$3: MMA8652FC

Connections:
+3V3: C1.1, C2.1, C4.1, RN4020.P$23 (VDD), U$1.P28 (VIN), U$3.P$1 (VDD), U$3.P$8 (VDDIO)
BLUETOOTH_TO_TEENSY: RN4020.P$5 (UART_TX), U$1.P10 (P8_DIN_TX3)
BLUETOOTH_WAKE_HW: RN4020.P$15 (WAKE_HW), U$1.P8 (P6_CS1)
CAP01: JP1.4, U$1.P24 (P22_A8_CS3)
CAP02: JP1.3, U$1.P3 (P1_TX1)
CAP03: JP1.2, U$1.P25 (P23_A9_CS2)
CAP04: JP1.1, U$1.P2 (P0_RX1)
CAP05: JP2.3, U$1.P17 (P15_A1_CS4)
CAP06: JP2.2, U$1.P18 (P16_A2_SCL)
CAP07: JP2.1, U$1.P19 (P17_A3_SDA)
GND: C1.2, C2.2, C3.2, C4.2, LED1.4 (BLUE_C), LED1.5 (RED_C), LED1.6 (GREEN_C), RN4020.P$1 (GND), RN4020.P$9 (GND), RN4020.P$16 (GND), RN4020.P$24 (GND), U$1.P1 (GND), U$3.P$6 (GND), U$3.P$7 (GND), U$3.P$9 (GND)
INT1: U$1.P23 (P21_A7_RX1_CS3), U$3.P$3 (INT1)
INT2: U$1.P22 (P20_A6_CS2), U$3.P$5 (INT2)
MISO: U$1.P14 (P12_DIN)
MOSI: U$1.P13 (P11_DOUT)
unnamed: C3.1, U$3.P$4 (BYP)
unnamed: LED1.2 (RED_A), R2.1
unnamed: R2.2, U$1.P6 (P4)
unnamed: LED1.3 (BLUE_A), U$1.P5 (P3)
unnamed: LED1.1 (GREEN_A), U$1.P7 (P5_TX1)
SCK: U$1.P15 (P13_LED_SCK)
SCL: U$1.P21 (P19_A5_SCL), U$3.P$2 (SCL)
SDA: U$1.P20 (P18_A4_SDA), U$3.P$10 (SDA)
SS: U$1.P12 (P10_CS0_TX2)
TEENSY_TO_BLUETOOTH: RN4020.P$6 (UART_RX), U$1.P9 (P7_DOUT_RX3)

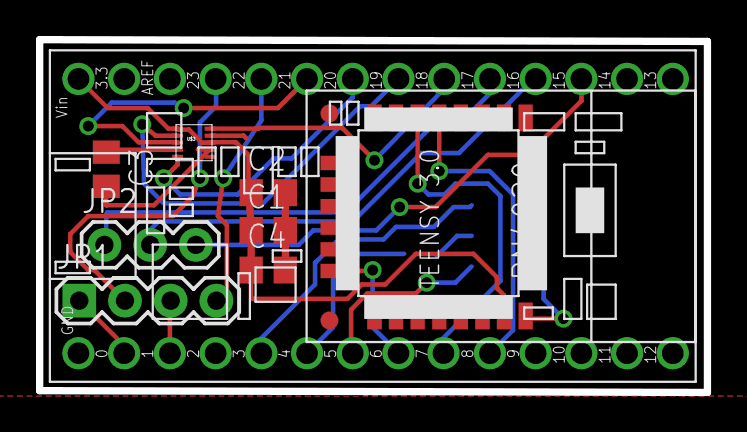
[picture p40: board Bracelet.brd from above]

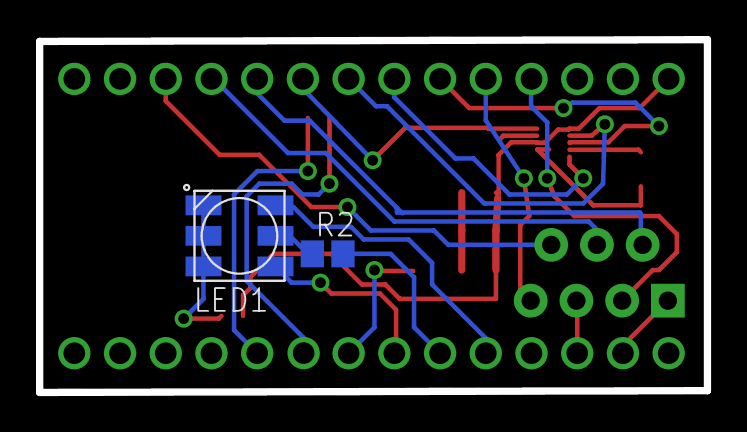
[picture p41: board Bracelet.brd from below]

Board: 2 copper layers, 37.1 x 19.6 mm, 11 parts (2 on the bottom side), 21 nets.

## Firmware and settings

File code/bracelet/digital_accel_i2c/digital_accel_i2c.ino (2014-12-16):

#include <i2c_t3.h>
#include <SoftwareSerial.h>
//#include "threedollar.h"
#include "TouchSlider.h"

/* Pin Configuration */
#define LED_R 4
#define LED_G 3
#define LED_B 5
#define BT_RX 7
#define BT_TX 8
#define BT_WAKE_HW 6
#define TOUCH_1 16
#define TOUCH_2 1
#define TOUCH_3 23
#define TOUCH_4 15
#define TOUCH_5 17
#define TOUCH_6 22
#define TOUCH_7 0

/* I2C Configuration */
#define ADDR         0x1D

/* Register Addresses */
#define CTRL_REG1    0x2A
#define PULSE_CFG    0x21
#define PULSE_SRC    0x22
#define PULSE_THSZ   0x25
#define PULSE_TMLT   0x26
#define PULSE_LTCY   0x27
#define PULSE_WIND   0x28
#define XYZ_DATA_CFG 0x0E
#define STATUS_REG   0x00
#define OUT_X_MSB    0x01
#define OUT_X_LSB    0x02
#define OUT_Y_MSB    0x03
#define OUT_Y_LSB    0x04
#define OUT_Z_MSB    0x05
#define OUT_Z_LSB    0x06

/* Bitmasks for Configuration and Status Checks*/
#define ACTIVE_MASK  0x01
#define DATA_RDY     0x04
#define TAP_Z_SINGLE_EN 0xD0
#define TAP_Z_DOUBLE_EN 0xE0
#define TAP_Z_S_MASK 0xC0
#define TAP_Z_D_MASK 0xC8ttslider
#define HPF_EN_MASK  0x10

/* Gesture Recognizer Configuration */
#define SAMPLE_SIZE 150 //number of samples per Gesture
#define DELAY_SIZE 10 //delay betweeen two samples

/* Capacitive Touch Configuration */
#define SEGMENT_COVER_THRESH 10 //number of cycles before a touch segment counts as touched !!!check this if delay functions are removed!

struct AccelData{
  int x;
  int y;
  int z;
};

AccelData gesture[SAMPLE_SIZE];
SoftwareSerial bluetooth(BT_RX, BT_TX);
const int TOUCH_PINS[] = {TOUCH_1, TOUCH_2, TOUCH_3, TOUCH_4, TOUCH_5, TOUCH_6, TOUCH_7};
TouchSlider tslider(7, TOUCH_PINS);
int touch_state[7]; //contains information on how long a touch element has been pressed
int red;
int green;
int blue;
int last_red;
int last_green;
int last_blue;

/* Wrapper Function for Reading the Contents of a Register */
uint8_t read_reg(uint8_t addr){
  Wire.beginTransmission(ADDR);
  Wire.send(addr);
  int res = Wire.endTransmission(I2C_NOSTOP);
  res = Wire.requestFrom(ADDR, 1);
  if(Wire.available())
    return Wire.readByte();
}

/* Wrapper Function for Storing a given Byte in a Register */
void write_reg(uint8_t addr, uint8_t val){
  Wire.beginTransmission(ADDR);
  Wire.send(addr);
  int res = Wire.endTransmission(I2C_NOSTOP);
  Wire.send(val);
  res = Wire.endTransmission(I2C_STOP);
}

/* Sets the Accelerometer to Standby Mode.
 * Many Configurations can only be done while in Standby Mode 
 */
void standby_mode(){
  write_reg(CTRL_REG1, read_reg(CTRL_REG1) & ~ ACTIVE_MASK);
}

/* Sets the Accelerometer to Active Mode and Enables Data Recording */
void active_mode(){
  write_reg(CTRL_REG1, read_reg(CTRL_REG1) | ACTIVE_MASK);
}

/* Converts a 12-bit 2's complement Number stored in 
 * two 8-bit Registers to a signed integer number.
*/
int bytes_to_int(uint8_t high, uint8_t low){
  uint16_t temp = (high << 8) + low;
  int factor = 1;
  
  if (high > 0x7F)
  {
    // negative number
    temp = (~ temp) + 1;
    factor = -1;
  }
  
  return (temp >> 4) * factor;
}

/* Returns a Struct containing X, Y, and Z Acceleration Data
 * for the Point in Time when the Function is called.
 */
struct AccelData get_acceleration_data(){
  struct AccelData data;
  
  uint8_t x_hi = read_reg(OUT_X_MSB);
  uint8_t x_lo = read_reg(OUT_X_LSB);
  
  data.x = bytes_to_int(x_hi, x_lo);
  
  uint8_t y_hi = read_reg(OUT_Y_MSB);
  uint8_t y_lo = read_reg(OUT_Y_LSB);
  
  data.y = bytes_to_int(y_hi, y_lo);  
  
  uint8_t z_hi = read_reg(OUT_Z_MSB);
  uint8_t z_lo = read_reg(OUT_Z_LSB);
  
  data.z = bytes_to_int(z_hi, z_lo);
  
  return data;
}

/* When a Pulse was detected, this checks if it was a
 * single or double tap and does stuff in each case.
 */
int process_pulse(uint8_t register_data){
  if(register_data & TAP_Z_S_MASK){ 
    if(register_data & 0x08){
      //signal double tap)
      analogWrite(LED_B, 255);
      delay(100);
      analogWrite(LED_B, 0);
      delay(50);
      analogWrite(LED_B, 255);
      delay(100);
      analogWrite(LED_B, 0);
      Serial.println("double tap");
      
      //record accelerometer data for the next SAMPLE_SIZE datasets
      analogWrite(LED_R, 255);
      Serial.println("start recording");
      for(int i = 0; i < SAMPLE_SIZE; i++){
        gesture[i] = get_acceleration_data();
        Serial.print(gesture[i].x / 1024.0);
        Serial.print(" ");
        Serial.print(gesture[i].y / 1024.0);
        Serial.print(" ");
        Serial.println(gesture[i].z / 1024.0);
        delay(DELAY_SIZE);
      }
      analogWrite(LED_R, 0);
      Serial.println("end recording");
      return 2; //double tap
    }
    else{
      //signal single tap
      analogWrite(LED_G, 255);
      delay(200);
      analogWrite(LED_G, 0);
      Serial.println("single tap");
      return 1; //single tap
    }
  }
  else{
    return 0; //no tap
  }  
}

/* After a cover was detected, this function is called.
 * It differentiates between the on/off hold and the dimming
 * gesture.
 */
void process_rotation(){
  float rotation[4]; //magic number!
  int i = 0;
  int rotation_count = 0;
  int mean_hold = 0;
  int debounce_onoff = 0;
  
  while(isCovered()){  
    AccelData data = get_acceleration_data();
    float x = data.x / 1024.0;
    float y = data.y / 1024.0;
    float z = (data.z / 1024.0) - 1; //subtract gravity
    rotation[i] = (atan(y / (sqrt(x*x + z*z))) * 4086) / 71; //x axis //<- use this!
    //look for twist
    float delta = rotation[((i-1) % 4)] - rotation[i];
    if((delta > 0.5) && (rotation[i] < -30.0)){ //more light
      Serial.print("<-- | ");
      Serial.println(rotation[i]);
      rotation_count++;
      //TODO dim
      red = red - red / 10;
      if(red < 0){
        red = 0;
      }
      green = green - green / 10;
      if(green < 0){
        green = 0;
      }
      blue = blue - blue / 10;
      if(blue < 0){
        blue = 0;
      }
    }
    else if((delta < -0.5) && (rotation[i] > -10.0)){ //less light
      Serial.print("--> | ");
      Serial.println(rotation[i]);
      rotation_count++;
      //TODO dim
      red = red + red / 10;
      if(red > 255){
        red = 255;
      }
      green = green + green / 10;
      if(green > 255){
        green = 255;
      }
      blue = blue + blue / 10;
      if(blue > 255){
        blue = 255;
      }
    }
    i = (i + 1) % 4;
    for(int k = 0; k < 7; k++){
      mean_hold += touch_state[i];
    }
    mean_hold /= 7;
    if((debounce_onoff == 0) && (mean_hold > 100) && (rotation_count < 10)){ //magic numbers!
      Serial.println("ON/OFF");
      debounce_onoff = 1;
      //on/off     
      if((red != 0) && (blue != 0) && (green != 0)){
        last_red = red;
        last_green = green;
        last_blue = blue;
        red = 0;
        blue = 0;
        green = 0;
      }
      else {
        red = last_red;
        green = last_green;
        blue = last_blue;
      }
    }
    send_to_lamp();
    delay(10);
  }
}

/* Checks if the whole touch surface is (still) covered */
int isCovered(){
  tslider.read();
  for(int i = 0; i < 7; i++){
    int val = tslider.getValue(i);
    if(val > 200){ //contact
      touch_state[i]++;
    }
    else if(touch_state[i] > 0){
      touch_state[i] = 0; //release contact
    }
  }
  int segments_covered = 0;
  for(int i = 0; i < 7; i++){
    if(touch_state[i] > SEGMENT_COVER_THRESH){
      segments_covered++;
    }
  }
  if(segments_covered >= 6){
    return 1;
  }
  else{
    return 0;
  }
}

/* changes the color mood to a given direction,
 * param indicates the direction
 * if param < 0, mood becomes more relaxing/blue
 * if param > 0, mood becomes more activating (orange/red)
 */
void process_mood_change(int param){
  //TODO change mood
  if(param < 0){ //increase blue, decrease red
    blue++;
    if(blue > 255){
      blue = 255;
    }
    red--;
    if(red < 0){
      red = 0;
    }
  }
  else if(param > 0){ //increase red, decrease blue
    red++;
    if(red > 255){
      red = 255;
    }
    blue--;
    if(blue < 0){
      blue = 0;
    }
  }
  
  send_to_lamp();
}

/* This function handles the precise color change
 * by tapping and sliding. Procedure is as follows:
 * 1. touch and hold the middle segment to activate
 *    this mode (implemented outside this function)
 * 2. slide to change hue
 * 3. tap on the electronics to change to the next
 *    parameter
 * 4. slide to set the saturation
 * 5. tap to confirm
 * 6. slide to set the lightness
 * 7. tap to confirm and exit this mode.
 * All changes are applied in real-time.
 */
void process_hue_change(){
  int pos = -1;
  int tap_detect = 0;
  int8_t pulse_data = 0;
  int hue = 0; //0 to 255
  int sat = 255; //0 to 255
  int lig = 128; //0 to 255
  int state = 0; //0 = hue, 1 = sat, 2 = lig
  
  Serial.println("Now slide for Hue!");
  while(state < 3){
  //change to sat/val by tap recognition
    pulse_data = read_reg(PULSE_SRC);
    if(pulse_data & 0x80){
      tap_detect = process_pulse(pulse_data);
    }
    if(tap_detect == 1){
      Serial.println("Next");
      state++;
      tap_detect = 0;
    }
    tslider.read();
    pos = tslider.getSliderPosition(); //ranges roughly from 22 to 70
    if(pos != -1){
      pos -= 22; //get rid of offset
      if(state == 0){
        hue = pos / 52.0 * 255;
        if(hue < 0){
          hue = 0;
        }
        if(hue > 255){
          hue = 255;
        }
        //Serial.println(hue);
      }
      else if(state == 1){
        sat = pos / 52.0 * 255;
        if(sat < 0){
          sat = 0;
        }
        if(sat > 255){
          sat = 255;
        }
        //Serial.println(sat);
      }
      else{
        lig = pos / 52.0 * 255;
        if(lig < 0){
          lig = 0;
        }
        if(lig > 255){
          lig = 255;
        }
        //Serial.println(lig);
      }
      change_color_hsl(hue, sat, lig);
    }
    delay(20);
  }
  analogWrite(LED_G, 255);
  analogWrite(LED_R, 255);
  analogWrite(LED_B, 0);
  delay(100);
  analogWrite(LED_R, 0);
  analogWrite(LED_G, 0);
  delay(50);
  analogWrite(LED_G, 255);
  analogWrite(LED_R, 255);
  delay(100);
  analogWrite(LED_R, 0);
  analogWrite(LED_G, 0);
  Serial.println("Done!");
}

/* Takes HSV parameters, transforms them to RGB and sends the result
 * to the associated lamp.
 */
void change_color_hsl(int hue, int sat, int lig){
  Serial.print("HSL: ");
  Serial.print(hue);
  Serial.print(sat);
  Serial.println(lig);
  int r, g, b;
  HSL_to_RGB(hue, sat, lig, &r, &g, &b);
  
  red = r;
  green = g;
  blue = b;
  send_to_lamp();
}

/* taken from http://qscribble.blogspot.de/2008/06/integer-conversion-from-hsl-to-rgb.html */
void HSL_to_RGB(int hue, int sat, int lum, int* r, int* g, int* b)
{
    int v;

    v = (lum < 128) ? (lum * (256 + sat)) >> 8 :
          (((lum + sat) << 8) - lum * sat) >> 8;
    if (v <= 0) {
        *r = *g = *b = 0;
    } else {
        int m;
        int sextant;
        int fract, vsf, mid1, mid2;

        m = lum + lum - v;
        hue *= 6;
        sextant = hue >> 8;
        fract = hue - (sextant << 8);
        vsf = v * fract * (v - m) / v >> 8;
        mid1 = m + vsf;
        mid2 = v - vsf;
        switch (sextant) {
           case 0: *r = v; *g = mid1; *b = m; break;
           case 1: *r = mid2; *g = v; *b = m; break;
           case 2: *r = m; *g = v; *b = mid1; break;
           case 3: *r = m; *g = mid2; *b = v; break;
           case 4: *r = mid1; *g = m; *b = v; break;
           case 5: *r = v; *g = m; *b = mid2; break;
        }
    }
}

void send_to_lamp(){
  //make sure all values have 3 digits and pad if necessary.
  Serial.print("LAMP: ");
  if(red < 100){
    if(red < 10){
      Serial.print("0");
    }
    Serial.print("0");
  }
  Serial.print(red);
  if(green < 100){
    if(green < 10){
      Serial.print("0");
    }
    Serial.print("0");
  }
  Serial.print(green);
  if(blue < 100){
    if(blue < 10){
      Serial.print("0");
    }
    Serial.print("0");
  }
  Serial.println(blue);
}

/* The usual setup stuff, setting pins, configuring the accelerometer
 * and starting serial communication.
 */
void setup(){
  pinMode(LED_R, OUTPUT);
  pinMode(LED_G, OUTPUT);
  pinMode(LED_B, OUTPUT);
  pinMode(BT_WAKE_HW, OUTPUT);
  
  digitalWrite(BT_WAKE_HW, HIGH);
  Serial.begin(9600);
  Wire.begin(I2C_MASTER, 0, I2C_PINS_18_19, I2C_PULLUP_INT, I2C_RATE_800);
  bluetooth.begin(2400);
  
  //config stuff
  write_reg(CTRL_REG1, 0x00); //to clear previous config
  //write_reg(XYZ_DATA_CFG, HPF_EN_MASK); //output high-pass filtered data
  
  //2g mode is default (1024 counts per g)
  
  //enable tap-detection on z-axis
  write_reg(PULSE_CFG, (TAP_Z_SINGLE_EN | TAP_Z_DOUBLE_EN));
  //configure tap detection threshold, with steps of 0.063g/LSB @+/-8g range
  write_reg(PULSE_THSZ, 100); //default: 100
  //maximum time interval between the start impulse and the end impulse of a tap
  //with steps of 0.625ms/LSB @800MHz ODR with normal power mode and no LP filtering
  write_reg(PULSE_TMLT, 10);
  //define time interval after pulse detection in which other pulses are ignored
  //with steps of 2.5ms/LSB @800MHz ODR with normal power mode
  write_reg(PULSE_LTCY, 10); //25ms
  //configure maximum time between two taps of a double tap
  //with steps of 2.5ms/LSB @800MHz ODR with normal power mode
  write_reg(PULSE_WIND, 200); //500ms
  
  active_mode();
  
  for(int i = 0; i < 7; i++){
    touch_state[i] = 0;
  }
  //start with white
  red = 100;
  green = 100;
  blue = 100;
  last_red = 100;
  last_green = 100;
  last_blue = 100;
  send_to_lamp();
}


void loop(){
  //need to save this because data is reset after reading
  uint8_t pulse_data = read_reg(PULSE_SRC);
  
  if(pulse_data & 0x80){
    process_pulse(pulse_data);
  }
  
  /* bluetooth stuff, doesn't work yet */
  if (bluetooth.available())
    Serial.write(bluetooth.read());
  if (Serial.available())
    bluetooth.write(Serial.read());
  
  
  /* capacitive touch stuff */  
  tslider.read();

  for(int i = 0; i < 7; i++){
    int val = tslider.getValue(i);
    if(val > 200){
      //touch at i
      //Serial.print("Touch at ");
      //Serial.println(i);
      touch_state[i]++;
    }
    else if(touch_state[i] > 0){ //touch released
      touch_state[i] = 0;
    }
  }
  
  //check for "cover touch"
  int segments_covered = 0;
  for(int i = 0; i < 7; i++){
    if(touch_state[i] > SEGMENT_COVER_THRESH){
      segments_covered++;
    }
  }
  if(segments_covered >= 6){
    process_rotation(); // <---!
    for(int i = 0; i < 7; i++){
      touch_state[i] = 1;
    }
  }

  //check for "mood change touch"
  if((touch_state[1] > 2*SEGMENT_COVER_THRESH) && (touch_state[2] > 2*SEGMENT_COVER_THRESH) && (touch_state[0] < SEGMENT_COVER_THRESH) && (touch_state[3] < SEGMENT_COVER_THRESH)){ //mood segment right
    Serial.println("Mood right");
    process_mood_change(1);
  }
  else if((touch_state[4] > 2*SEGMENT_COVER_THRESH) && (touch_state[5] > 2*SEGMENT_COVER_THRESH) && (touch_state[3] < SEGMENT_COVER_THRESH) && (touch_state[6] < SEGMENT_COVER_THRESH)){ //mood segment left
    Serial.println("Mood left");
    process_mood_change(-1);
  }
  
  //check for hue change activation touch (middle segment)
  if((touch_state[3] > 2*SEGMENT_COVER_THRESH) && (touch_state[2] < SEGMENT_COVER_THRESH) && (touch_state[4] < SEGMENT_COVER_THRESH)){
    Serial.println("Hue");
    process_hue_change();
  }
  delay(10);
}

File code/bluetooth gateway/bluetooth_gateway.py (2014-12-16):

# This is a gateway for Bluetooth communication over serial connection,
# since the Bluetooth module in the bracelet is currently not working.
# Color control data sent over USB serial is forwarded to the connected
# Bluetooth device via serial profile.
# In addition, this code also handles gesture recognition.

import serial
import onedollar

# CONFIG
#BRACELET_ADDR = '/dev/ttyACM0'
BRACELET_ADDR = 'COM9'
#BLUETOOTH_ADDR = '/dev/ttyACM1'
BLUETOOTH_ADDR = 'COM4'

# read gesture data from file
# each line must contain x, y, z values
# separated by spaces
def file2gesture(fname):
	f = open(fname, "r")
	data = f.readlines()
	gesture = []
	for line in data:
		coords = line.split(' ')
		p = onedollar.Point(float(coords[0]), float(coords[1]), float(coords[2].strip('\n')))
		gesture.append(p)
	#recognizer preprocessing
	gesture = onedollar.resample(gesture, 64) #magic number for the start
	gesture = onedollar.rotate_to_zero(gesture)
	gesture = onedollar.scale_to_square(gesture, 100) #magic number from 3$ paper
	gesture = onedollar.translate_to_origin(gesture)
	f.close()
	return gesture

bracelet = serial.Serial(BRACELET_ADDR, 9600)
bt = serial.Serial(BLUETOOTH_ADDR, 9600)
templates = []
#circles
templates.append(file2gesture("74.txt")) #circle[24], jan
templates.append(file2gesture("135.txt")) #circle[45], henning
templates.append(file2gesture("27.txt")) #karo
templates.append(file2gesture("42.txt")) #oli
templates.append(file2gesture("105.txt")) #sync
templates.append(file2gesture("180.txt")) #imp
templates.append(file2gesture("201.txt")) #mcsilver
templates.append(file2gesture("227.txt")) #hut

#pigatils
templates.append(file2gesture("21.txt")) #karo
templates.append(file2gesture("114.txt")) #sync
templates.append(file2gesture("59.txt")) #oli
templates.append(file2gesture("90.txt")) #jan
templates.append(file2gesture("144.txt")) #henning
templates.append(file2gesture("177.txt")) #imp
#templates.append(file2gesture("209.txt")) #mcsilver
templates.append(file2gesture("245.txt")) #hut

#zorros
templates.append(file2gesture("40.txt")) #oli
templates.append(file2gesture("6.txt")) #karo
templates.append(file2gesture("64.txt")) #jan
templates.append(file2gesture("97.txt")) #sync
templates.append(file2gesture("130.txt")) #henning
templates.append(file2gesture("158.txt")) #imp
#templates.append(file2gesture("185.txt")) #mcsilver
templates.append(file2gesture("224.txt")) #hut


while True:
	line = bracelet.readline().decode('ascii')
	print(line.encode())
	if line == "start recording\r\n": # gesture recognition
		gesture = []
		for i in range(150): #current sample size is 150
			line = bracelet.readline().decode('ascii')
			line = line.replace('\r', '')
			coords = line.split(' ')
			p = onedollar.Point(float(coords[0]), float(coords[1]), float(coords[2].strip('\n')))
			gesture.append(p)
		print("end recording")
		gesture = onedollar.resample(gesture, 64)
		gesture = onedollar.rotate_to_zero(gesture)
		gesture = onedollar.scale_to_square(gesture, 100)
		gesture = onedollar.translate_to_origin(gesture)
		#print("Gesture length: " + str(len(gesture)))
		result = onedollar.recognize(gesture, templates, 100)
		#print("score: " + str(result[1]))
		match = templates.index(result[0])
		print(match)
		if match < 8: #circle
			print("circle")
			#bracelet.write("circle\n".encode())
			bt.write("255050000\n".encode())
		elif match < 15: #pigtail
			print("pigtail")
			#bracelet.write("pigtail\n".encode())
			bt.write("150000150\n".encode())
		else:
			print("zorro")
			#bracelet.write("zorro\n".encode())
			bt.write("255255255\n".encode())
		#TODO return the corresponding shape
		#bracelet.write(match)
	elif line.startswith("LAMP"): #lamp color change command
		#the first 6 chars can be omitted, they are always "LAMP: "
		line = line[6:]
		line = line.replace('\r','')
		#print(line.encode())
		bt.write(line.encode())
		
		
		

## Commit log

2014-05-20 added freecad files and stl of first prototype model
    [01_simple_cuff.FCStd, 01_simple_cuff.stl, 01_simple_cuff_no_fillets.stl]
2014-05-20 added freecad files and stl of second prototype
    a more comfortable cuff with smaller and flatter ends.
    [02_comfortable_cuff.FCStd, 02_comfortable_cuff.stl]
2014-05-20 added solidworks and stl files for amico bracelet
    source:
    https://grabcad.com/library/amico-bracelet--9
    by Daniel Muschke
    [03_amico_bracelet.stl, 03_amico_front.stl, 03_amico_side.stl]
2014-05-20 added freecad and stl files for a tri-part model
    the stl files have some issues on the mirror axis.
    [04_tri_part_assembly.FCStd, 04_tri_part_end.FCStd, 04_tri_part_end.stl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]
2014-05-20 missed a fusion which resulted in bad stl files
    [04_tri_part_end.FCStd, 04_tri_part_end.stl, 04_tri_part_middle.FCStd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]
2014-05-23 new revision of tri part bracelet
    features:
    - bigger (actually wearable)
    - additional holes for wiring
    turned out to be too big :/
    [04a_tri_part_middle.FCStd, 04b_tri_part_end.FCStd, 04b_tri_part_end.stl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]
2014-06-16 Cuff with lid, also increased the diameter.
    [02a_confortable_cuff_improved.FCStd, 02a_confortable_cuff_improved.stl, 02a_lid.FCStd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]
2014-07-02 arduino code for the lamp thingy
2014-07-07 Running into bluetooth issues -.-
    [lamp_shield_test.ino]
2014-07-09 Simple test sketch for bluetooth connection. Outputs everything entered on Arduino serial on bt serial.
2014-07-09 Schematic for the Lamp setup.
    [Lamp.fzz]
2014-07-10 silicone bracelet and mold
    [05_silicone_bracelet_mold.FCStd, 05_silicone_bracelet_moldable.FCStd]
2014-07-10 new mold, round.
    [06_mold2.FCStd]
2014-07-16 new mold
    [06_mold2.FCStd, 06_mold2_base.FCStd, 06_mold2_base.stl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]
2014-07-21 new silicone mold.
    [06a_inner.stl, 06a_mold2_improved.FCStd, 06a_mold2_improved_inner.FCStd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]
2014-07-21 adaption to the manufactured pcb. doesn't work yet.
    [lamp_shield_test.ino]
2014-07-23 switching back to software serial for bluetooth.
2014-07-23 switching back to softwareserial.
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2014-08-14 touch slider code for teensy by henning
2014-08-14 svg schematic for a touch slider
2014-08-14 3d accelerometer testing code.
2014-08-20 preperations for gesture recognition: sample on button press. next step: save data somewhere, build a knowledge base, implement gesture recognition algorithm.
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2014-08-21 some experimentations and gesture recording.
    next: how to store some kind of knowledge base on the teensy.
2014-08-27 Wrote part about CAD.
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2014-09-24 RGB LED breakout board files and stuff. Successfully etched!
    [led breakout.brd, led breakout.sch]
2014-09-26 Had wrong pin headers (too small), but worked out since the difference is not that big and there are only 3 pins on each side.
    [led breakout.brd, led breakout.sch]
2014-09-26 New breakout board for MMA8652 digital accelerometer.
    [mma_breakout.brd, mma_breakout.sch]
2014-09-26 added RGB LED test lines.
2014-09-30 stencil files for mma breakout board
2014-10-01 yet another stencil file I used for successful laser cutting
2014-10-02 minimal test script for the digital accelerometer breakout board. receives only zeroes atm.
2014-10-07 started with some helper functions for accelerometer config and control.
2014-10-07 did some testing, nothing woks. even active mode does not set. checked the wiring and everything seems to be ok.
2014-10-09 changed library to the modified version of Wire for Teensy.
    Read works!
2014-10-09 bugfix: two function names were switched -.-
    also changed types from byte to uint8_t because
    that's what comes out of the (new) Wire functions.
    Some cleanup and testing, works fine.
    [digital_accel_i2c.ino]
2014-10-09 code for reading acceleration data and converting to signed int numbers.
    refuses to compile with "stuct does not name a type" error. sigh.
    [digital_accel_i2c.ino]
2014-10-10 fix struct error and removed some debug lines.
    [digital_accel_i2c.ino]
2014-10-10 this accelerometer is unroutable. the rest is fine.
    [Bracelet.brd, Bracelet.sch]
2014-10-10 finished layout, accel pullups need to be conf'ed to internal.
    [Bracelet.brd, Bracelet.sch]
2014-10-10 activated internal pullup resistors
2014-10-10 added a simple pushbutton for increased number of options. I strongly hope that we own smd 2-pin pushbuttons in stock...
    [Bracelet.brd, Bracelet.sch]
2014-10-13 finished bracelet design and etched a board.
    [Bracelet.brd]
2014-10-15 new bracelet version with slightly broader wires next to the accelerometer. since they always broke :(
    [Bracelet.brd]
2014-10-15 updated laser svgs accordingly.
2014-10-15 generated stencil files and removed switch and bluetooth pads.
2014-10-16 new bracelet version! - new teensy only with needed pads - no button - no unnecessary multipliers at the LED - broader circuits - pcb is much smaller
    [Bracelet.brd, Bracelet.sch]
2014-10-17 added z tap detection.
    works, but is very sensitive atm. next idea: use high-pass filtered data.
2014-10-17 added some tap configs.
    still not working as intended, especially double tap detection fails.
    [digital_accel_i2c.ino]
2014-10-20 some parameter fiddling for accelerometer calibration
2014-10-20 new cad model for teensy with shield.
    [07_teensy_with_board.FCStd]
2014-10-22 new cad model for a new cast.
    [07_base_mold.FCStd, 07_base_mold.stl, 07_bracelet_positivr.FCStd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]
2014-10-22 dummy section for teensy
2014-10-31 porting the one dollar algorithm to the three dollar algorithm.
    GSS is the last big issue, afterwards testing can begin.
    [onedollar.py]
2014-10-31 added sample data for some gestures
    those were recorded wearing the current bracelet
    prototype. sould be okay for testing the 3$ recognizer
2014-11-03 fixed a little error
    [onedollar.py]
2014-11-03 started implementing the actual recognizer and encountered some errors.
    will fix them tomorrow.
    [onedollar.py, recognizer.py]
2014-11-05 parameter fiddling and high pass filter enable
2014-11-06 next revision for braclet board, now dual layer.
    [Bracelet.brd, Bracelet.sch]
2014-11-06 finished board layout and created gerber files.
    [Bracelet.brd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]
2014-11-07 skeleton file for teensy project extension
2014-11-08 excluded some eagle dotfiles from gitignore
    not sure which are necessary for pcb manufacturing....
2014-11-10 disabled high-pass filtering and recorded some test data
    1-10 are a 90° angle, 11-20 are arcs and 21-30 are circles.
    plotted and looks quite okay, but here and there
    are some outliers.
    possibly the accelerometer wasn't soldered properly.
2014-11-11 work in progress.
    recognizing is wrong atm, probably due to bad rotation.
    I picked up a matrix from the 3$ reference implementation
    and can derive Euler axis and angle from that.
    Tomorrow will be algebra-day!
    [onedollar.py, recognizer.py]
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2014-11-13 enabled HPF again and corrected some recognizer code for teensy
    [digital_accel_i2c.ino]
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2014-11-18 new bracelet
    [08_base.FCStd, 08_inner.stl, 08_inner_mold.FCStd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]
2014-12-04 finished rotation and on/off code. things still missing are color mood change and fine interaction.
    [digital_accel_i2c.ino]
2014-12-08 some dirty fix for incorrect lengths and a division by zero fi.
    [onedollar.py]
2014-12-09 reworked prototype sections and wrote touch sensor section and started accelerometer section.
2014-12-09 added blacklist for template picking, so that gestures that already are templates won't get recommended again.
    [pick_templates.py]
2014-12-09 fixed hsv stuff by pasting some code. added lamp output. still some todos left.
    [digital_accel_i2c.ino]
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2014-12-10 minimal test for bluetooth gateway, copy of the onedollar lib and some corrections. should work.
    [bluetooth_gateway.py, onedollar.py]
2014-12-10 adjusted serial speed, the bluetooth link to arduino seems quite slow.
2014-12-11 writing, some new pictures, an improved picture and a new reference for i2c.
2014-12-15 fixed some issues in lamp controlling code, various debug information
    [bluetooth_gateway.py, digital_accel_i2c.ino, lamp_shield_test.ino]
2014-12-15 another template picking metric: correct/fp ratio
    [pick_templates.py]
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2015-05-14 outsourced breakout boards
    [led breakout.brd, led breakout.sch, mma_breakout.brd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]

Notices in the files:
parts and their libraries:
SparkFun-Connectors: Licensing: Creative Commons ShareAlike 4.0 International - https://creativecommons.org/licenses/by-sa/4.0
